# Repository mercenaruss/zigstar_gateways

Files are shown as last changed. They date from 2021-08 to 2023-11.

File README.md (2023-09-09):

# ZigStar Zigbee Gateways
Information and documentation on ZigStar gateways is available on [Website](https://zig-star.com) <br/> 
Pre-assembed hardware devices can be purchased from [https://zig-star.com](https://zig-star.com) and on [Tindie](https://www.tindie.com/stores/zigstar/)<br />



ZigStar Zigbee Gateways have next features:

-   It's using CC2652P TI chip from TI, the most powerful (+20dB)
-   **2 WORKING MODES:** LAN Coordinator or USB Coordinator/Router
-   Required buttons are on board (BOOT,FLASH,RESET)
-   2 LED for indication of network
-   Communicates via USB or LAN network with  [Z2M](https://www.zigbee2mqtt.io/)  and  [ZHA](https://www.home-assistant.io/integrations/zha/)
-   SMA port for an external antenna
-   Easy programming with  [ZigStar Multi Tool](https://zig-star.com/radio-docs/zigstar-multi-tool/#zigstar-multi-tool).No external programmer needed!
-   All boards are OpenSource,ready for self assembly

## Active Devices
| Picture 	| Device 	| Description 	| Working Mode 	|
|---	|---	|---	|---	|
| uzg-01  	| [UZG-01](https://uzg.zig-star.com/) 	| Custom device without modules 	| USB/LAN/WIFI 	|
| lan-gateway  	| [ZigStar LAN Gateway](https://zig-star.com/projects/zigbee-gw-lan/) 	| CC2652P2 & WT32-ETH01 ESP32 	| USB/LAN 	|
| usb-stick 	| [ZigStar Stick v4](https://zig-star.com/projects/zigbee-stick-v4/) 	| CC2652P2 	| USB 	|

## Retired devices
| Picture 	| Device 	| Description 	| Working Mode 	|
|---	|---	|---	|---	|
| poe-gateway 	| [ZigStar OliZig PoE](https://zig-star.com/projects/zigstar-olizig/) 	| CC2652P2 & Olimex ESP32-PoE 	| USB/LAN/POE  	|
| poe-gateway 	| [ZigStar LilyZig PoE](https://zig-star.com/projects/zigstar-lilyzig/) 	| CC2652P2 & TTGO T-Internet-POE 	| USB/LAN/POE  	|

## Development

For all documentation,description and instructions visit: [ZIG-STAR.COM](https://zig-star.com)<br>
In case you want to help us improve documentation please check documentation subfolder.

## Contact

For general enquiries, suggestions and errors spotted contact me using:

- [Telegram Chat](https://t.me/zig_starting)

- [Telegram News](https://t.me/zigstar)

- [Twitter](https://twitter.com/zig_star4u)

- [Discord](https://discord.gg/zPMT3GvvdC)

- [support@zig-star.com](mailto:support@zig-star.com)

### License
zigstar-gateways is designed by ZigStar / Grecu Radu and licensed under the [GPL-3.0 License](https://opensource.org/licenses/GPL-3.0).

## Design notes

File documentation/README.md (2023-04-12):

# ZigStar Gateways -  Documentation

This subfolder contains the [zig-star.com](https://zig-star.com) documentation.
It is based on [Mkdocs](https://www.mkdocs.org/) & [Material for MkDocs](https://squidfunk.github.io/mkdocs-material/)

You are very welcome to help on improving documentation.

## Directory-Structure

* `docs`: The actual documentation.
* `overrides`: MkDocs enhancements.
* `mkdocs.yaml`: MkDocs config file
* `init_setup.sh`: Prepare venv enviroment 
* `requirements.txt`: Mkdocs requirements

## Mkdocs installation

```bash
# Install MkDocs dependencies Linux
bash init_setup.sh
```

Manual installation:
```bash
# Install MkDocs dependencies Windows
python3 -m venv venv
. venv/Scripts/activate
pip install mkdocs-material
```

## Live preview of changes

From documentation folder run next commands:
```bash
# Enter in virtual enviroment
. venv/bin/activate ##For Linux
. venv/Scripts/activate  ## For windows
# Run mkdocs serve command to generate live preview
mkdocs serve
```

## Requirements:

- Python 3.8+
- pip

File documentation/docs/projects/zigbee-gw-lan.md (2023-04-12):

---
title: ZigStar LAN Gateway
description: Zigbee LAN Coordinator based on CC2652P
tags:
  - zigbee gateway lan
  - zigbee ethernet gateway
  - zigbee lan bridge
  - ethernet zigbee
  - zigbee ethernet
  - lan coordinator
hide:
  - tags
  - toc
---

<div class="swiper stick">
      <div class="swiper-wrapper">
        <div class="swiper-slide">
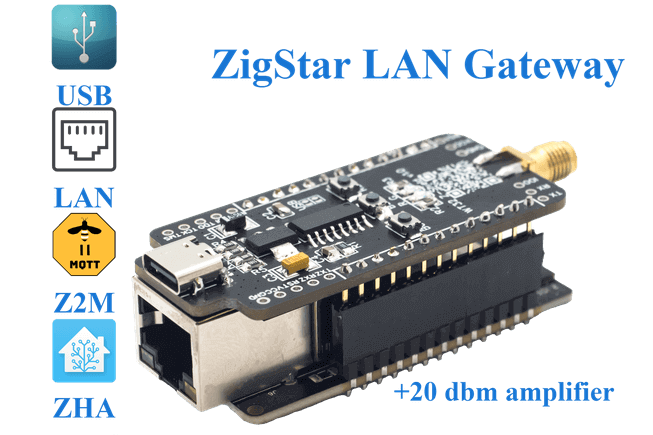
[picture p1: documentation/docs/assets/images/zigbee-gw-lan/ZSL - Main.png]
”zigbee
          
        </div>
    <div class="swiper-slide">
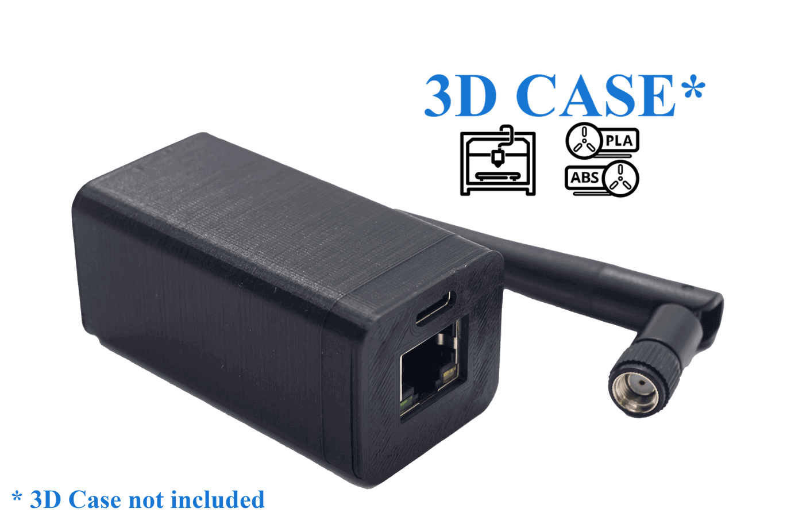
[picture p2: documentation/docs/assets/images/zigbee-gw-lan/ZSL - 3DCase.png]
”zigbee
          
        </div>
      </div>

    </div>

## Features

- Wide range of Zigbee Modules (CC2652P, CC2652RB, etc)
- <b> 2 WORKING MODES: </b> LAN Coordinator or USB Coordinator/Router
- BOOT,FLASH,RESET Buttons
- 2 LED for indication [Custom firmware](https://github.com/jethome-ru/zigbee-firmware/tree/master/ti/coordinator/cc2652)
- Communicates via USB or LAN network with [Z2M](https://www.zigbee2mqtt.io/) and [ZHA](https://www.home-assistant.io/integrations/zha/)
- SMA port for an external antenna
- Easy programming with [ZigStar Multi Tool](/radio-docs/zigstar-multi-tool/#zigstar-multi-tool).No external programmer needed!<br>
- Plug & Play, comes pre-flashed

## Revisions

There are 3 version of Zigbee LAN Gateway,what are tested:<br>
- [RF-STAR RF-BM-2652P2 - 20dBm](https://github.com/mercenaruss/zigstar_gateways/raw/main/files/Gerbers/LAN%20Gateway/Gerber_WT32_RF-BM-2652P2.zip)<br>
- [Ebyte E72-2G4M20S1E  - 20dBm](https://github.com/mercenaruss/zigstar_gateways/raw/main/files/Gerbers/LAN%20Gateway/Gerber_WT32_E72-2G4M20S1E.zip)<br> 
- [Ebyte E72-2G4M05S1F  - 5dBm](https://github.com/mercenaruss/zigstar_gateways/raw/main/files/Gerbers/LAN%20Gateway/Gerber_WT32_E72-2G4M05S1F.zip)[^1]<br>

!!! INFO
    - RF-STAR RF-BM-2652P2 recommended
	  - PCB thickness 1.2mm is recommended

## Bill of Materials

EasyEDA Generated BOM,you can order on [LCSC](https://lcsc.com) directly - [BOM](https://github.com/mercenaruss/zigstar_gateways/blob/main/files/BOM/BOM_WT32_RF-BM-2652P2.csv)

| Designator  | Name  | Footprint | Quantity |
| :---|:---|:-----|:---:|
| U1|[RF-BM-2652P1/P2](https://letyshops.com/r/aliexpress-c83c7878b18b)| | 1 |
| U2|[WT32-ETH01](https://letyshops.com/r/aliexpress-73b6cc1c03c9) |N/A| 1 |
| U3 | CH340C|SOP-16 |1|
| U4 | AMS1117-3.3|SOT-223 |1|
| R1 | 10 kohm|SMD 0805 |1|
| R2,R3 | 1 kohm|SMD 0805 |2|
| R4,R5 | 5.1 kohm|SMD 0805 |2|
| R6,R7 | 22 ohm|SMD 0805 |2|
| C1| 10uF|SMD_L3.5-W2.8|1|
| C2,C4| 100nF|SMD 0805|2|
| C3| 22uF|SMD_L3.5-W2.8|1|
| L1,L2| RED/GREEN LED|SMD 0805|2|
| SBL,RST,BOOT|PUSH BUTTON |SMD_L3.9-W3.0-P4.45|3|
| USB| TYPE-C|USB-C_SMD-TYPE-C-31-M-12|1|
| CON| [STACKABLE HEADER 13 PIN](https://letyshops.com/r/aliexpress-09c274fbb012) |2.54x13P|1|
| ANT| [SMA ANTENNA PORT 1.2mm](https://letyshops.com/r/aliexpress-e6704ce906c0)|SMA EDGE|1|

Next items are not available on LCSC,you can get them on Aliexpress:

| Name  | Shop 1 | Shop 2 |
| :---|:---|:-----|
| WT32-ETH01| [CLICK](https://letyshops.com/r/aliexpress-a4dd8609c8d4)| [CLICK](https://letyshops.com/r/aliexpress-401d07dc02d1) |
| RF-STAR RF-BM-2652P1/P2|[CLICK](https://letyshops.com/r/aliexpress-dbe513b72282) | [CLICK](https://letyshops.com/r/aliexpress-1f3e1a35e82d) |
| Ebyte E72-2G4M20S1E | [CLICK](https://letyshops.com/r/aliexpress-b25ea4b8642a)| [CLICK](https://letyshops.com/r/aliexpress-00563b7dcf47) |
| Ebyte E72-2G4M05S1F | [CLICK](https://letyshops.com/r/aliexpress-dd63f3c1afdc)| [CLICK](https://letyshops.com/r/aliexpress-c8b5adc0e26c) |
| RP-SMA Antenna PCB Connector 1.2mm | [CLICK](https://letyshops.com/r/aliexpress-7507f61580c3)| N/A |
| RP-SMA Antenna Female - Inner hole |[CLICK](https://letyshops.com/r/aliexpress-81d294a1360f)| [CLICK](https://letyshops.com/r/aliexpress-5ebae68206ac) |
| STACKABLE FEMALE HEADER 13 PIN| [CLICK](https://letyshops.com/r/aliexpress-fb2fa1673785) | [CLICK](https://letyshops.com/r/aliexpress-09c274fbb012) |

## Options

In order to use your LAN Gateway in USB Mode(without connection to WT32-ETH01):<br>
Solder jumpers, labeled J1/USB or change default DIP switch position

!!! danger "DIP Switch Positions"
    - <b>ON</b> for USB Mode
	  - <b>OFF</b> for LAN Mode<br>

    Both switches should be in the same position.
  
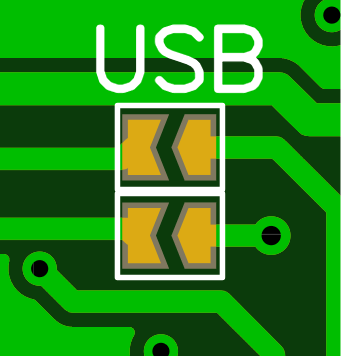
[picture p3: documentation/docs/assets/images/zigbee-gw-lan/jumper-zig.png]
Jumper-Zigbee
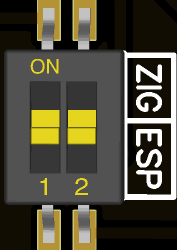
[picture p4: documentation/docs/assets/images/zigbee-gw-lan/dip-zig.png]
Jumper-Zigbee
  

## Firmware

Help on choosing correct firmware for your device is located [HERE](/radio-docs/quick-start/#step-2-download-the-correct-firmware-for-your-device)

## Flashing

* [YAML Config](https://github.com/mercenaruss/zigstar_gateways/blob/main/files/ESP-HOME/zigstar-gw-lan.yaml)<br>
* [WT32-ETH01 Firmware ESP-Home](https://github.com/mercenaruss/zigstar_gateways/raw/main/files/ESP-HOME/zigstar-gw-lan.bin)<br> 
* [ZigStar Firmware](https://github.com/xyzroe/ZigStarGW-FW/releases)[^2]<br> 
* ESP-HOME flashing guide - [ESP-HOME](/radio-docs/esp-home/)<br>
* ZigStar flashing guide - [ZigStar Firmware](/radio-docs/flash-zigstargw/)<br>
* Zigbee Module flashing guide - [ZigStar Multi Tool](/radio-docs/zigstar-multi-tool/#zigstar-multi-tool))<br>

## Downloads
 - [Gerbers](https://github.com/mercenaruss/zigstar_gateways/tree/main/files/Gerbers)
 - [STL Case](https://github.com/mercenaruss/zigstar_gateways/tree/main/files/STL)
 - [Schematics (pdf)](https://github.com/mercenaruss/zigstar_gateways/tree/main/files/Schematics)
 - [LCSC BOM File](https://github.com/mercenaruss/zigstar_gateways/tree/main/files/BOM)

## Video

*English subtitles available

1. Ethernet Zigbee ZigStar Gateway, installing multiple zigbee2mqtt<br>

	<iframe width="560" height="315" src="https://www.youtube-nocookie.com/embed/KBEaVZyvSgY" title="YouTube video player" frameborder="0" allow="accelerometer; autoplay; clipboard-write; encrypted-media; gyroscope; picture-in-picture" allowfullscreen></iframe>

2. Server redundancy with Zigbee2MQTT on Zigbee LAN Coordinator Zigstar<br>

	<iframe width="560" height="315" src="https://www.youtube-nocookie.com/embed/g7BpjCrOhk8" title="YouTube video player" frameborder="0" allow="accelerometer; autoplay; clipboard-write; encrypted-media; gyroscope; picture-in-picture" allowfullscreen></iframe>
	
[^1]: **Not recommended for new assembly.**
[^2]: **All forces will be used for this firmware, ESPHOME debugging and development is depreceated**

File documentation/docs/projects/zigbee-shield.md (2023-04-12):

---
title: ZigStar Shield
description: Zigbee Shield (CC2652P Zigbee Coordinator) Design Files and Description, working with Zigbee2Mqtt (Z2M) and ZHA
---

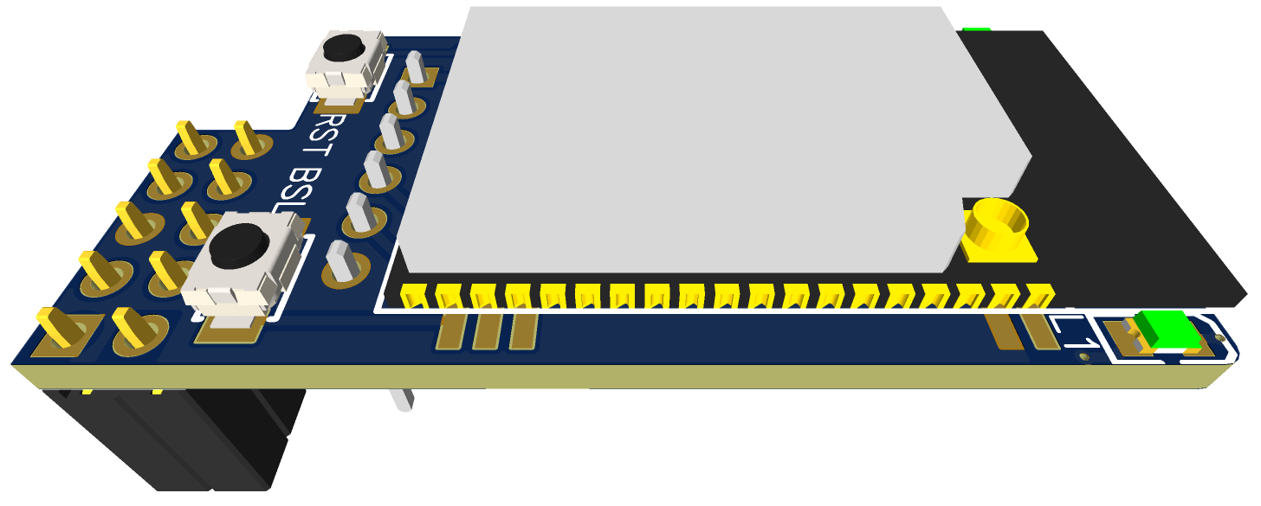
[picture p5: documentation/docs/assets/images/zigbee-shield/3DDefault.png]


## Features

- [TI CC2652P](https://www.ti.com/product/CC2652P)SimpleLink™ 2.4 GHz Multiprotocol Wireless MCU targeting Zigbee,Bluetooth 5.1 Low Energy,Thread + 19.5-dBm high-power amplifier
- Support RF-BM-2652P1 and RF-BM-2652P2 Module from RF-STAR,with CC2652P on board
- BSL,RST Buttons
- 2 LED for indication
- Compatible with [Z2M](https://www.zigbee2mqtt.io/) and [ZHA](https://www.home-assistant.io/integrations/zha/)
- IPX port for an external antenna
- Self-programming via [cc2538-bsl](https://github.com/JelmerT/cc2538-bsl). No external programmer needed! Push BSL button to trigger this mode.

## Bill of Materials:

EasyEDA Generated Boom,you can order on [LCSC](https://lcsc.com)directly - [BOOM](https://github.com/mercenaruss/zigbee-stick-v4/blob/main/files/BOM_ZigStar_Shield.csv)

| Designator  | Name  | Footprint | Quantity |
| :---|:---|:-----|:---:|
| U1| RF-BM-2652P1/P2| | 1 |
| U2|AMS1117-3.3 |SOT-223| 1 |
| R1 | 10 kohm|SMD 0805 |1|
| R2,R3 | 1 kohm|SMD 0805 |2|
| C1| 10uF|SMD_L3.5-W2.8-R-RD|1|
| C2| 22uF|SMD_L3.5-W2.8-R-RD|1|
| C3| 100nF|SMD 0805|1|
| L1,L2| RED/GREEN LED|SMD 0805|2|
| SBL,RST|PUSH BUTTON |SMD_L3.9-W3.0-P4.45|2|
| JTAG| PIN HEADER 5 PIN|2.54x5P|1|
| H1| FEMALE HEADER 2x5 PIN|2.54 2x5P|1|

Next item is not available on LCSC,you can get it on Aliexpress:

 - [RF-BM-2652P1/P2](https://letyshops.com/r/aliexpress-f6e2c6d280d5)
 
## Firmware

Module is compatible with [Z2M](https://www.zigbee2mqtt.io/).
Firmware [CC1352P2_CC2652P_launchpad_*.zip](https://github.com/Koenkk/Z-Stack-firmware/tree/master/coordinator/Z-Stack_3.x.0/bin).<br>
Default TX Power is <b>5dbm</b>. It can be adjusted in Z2M config section:

    experimental:
      transmit_power: 5

Available TX power values: -20,-18,-15,-12,-10,-9,-6,-5,-3,0,1..5,14..20

## Downloads
 - [Gerber](https://github.com/mercenaruss/zigbee-stick-v4/tree/main/files/gerber)
 - [Schematics (pdf), Revision 1](https://github.com/mercenaruss/zigbee-stick-v4/tree/main/files/schematics)
 - [LCSC Boom File](https://github.com/mercenaruss/zigbee-stick-v4/blob/main/files/BOM_ZigStar_Shield.csv)

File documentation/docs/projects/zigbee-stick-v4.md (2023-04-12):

---
title: ZigStar Stick v4
description: Zigbee USB Stick - CC2652P Zigbee Coordinator
tags:
  - zigbee stick
  - zigbee usb-stick
  - usb zigbee gateway
  - zigbee dongle
  - zigbee coordinator
hide:
  - tags
  - toc
---
<div class="swiper stick">
      <div class="swiper-wrapper">
        <div class="swiper-slide">
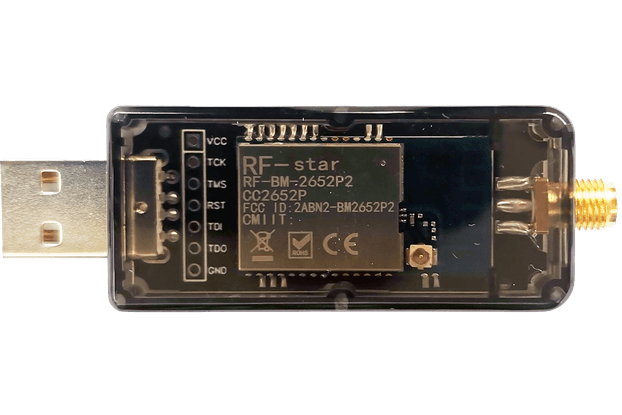
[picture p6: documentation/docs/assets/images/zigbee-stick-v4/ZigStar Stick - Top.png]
”zigbee
          
		  <div class="title" id="title_1">ZigStar Stick - Top</div>
        </div>
        <div class="swiper-slide">
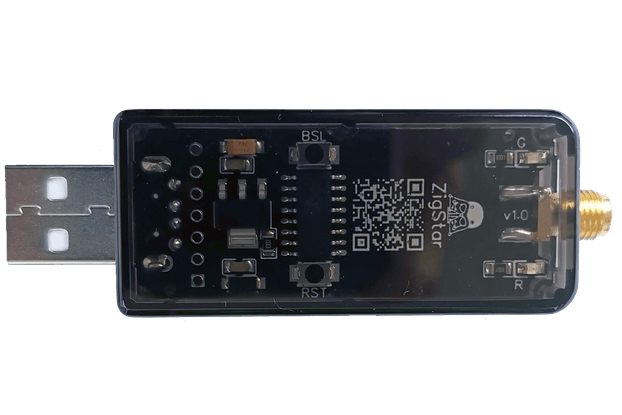
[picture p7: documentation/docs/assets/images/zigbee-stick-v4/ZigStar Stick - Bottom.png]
”cc2652p
          
		  <div class="title" id="title_2">ZigStar Stick - Bottom</div>
        </div>
      </div>

    </div>

## Features

- [TI CC2652P](https://www.ti.com/product/CC2652P) SimpleLink™ 2.4 GHz Multiprotocol Wireless MCU targeting Zigbee,Bluetooth 5.1 Low Energy,Thread + 19.5-dBm high-power amplifier<br>
- Support RF-BM-2652P1 and RF-BM-2652P2 Module from RF-STAR,with CC2652P on board<br>
- BSL,RST Buttons<br>
- 2 LED for indication<br>
- Compatible with [Z2M](https://www.zigbee2mqtt.io/)and [ZHA](https://www.home-assistant.io/integrations/zha/)<br>
- SMA antenna port for an external antenna<br>
- Easy programming with [ZigStar Multi Tool](/radio-docs/zigstar-multi-tool/#zigstar-multi-tool).No external programmer needed!<br>
- Communicates via the common CH340E/CH340C USB-UART Bridge<br>
- Plug & Play, comes pre-flashed<br>

## Purchase 

Assembled versions of Zigbee Stick v4 is available for purchase.<br>
<b>Shiping is done from Germany</b><br>
Each order contains a fully assembled and tested PCBA along with a plastic enclosure and a small +3dBi antenna.

## Revisions

There are 2 versions of stick,both of them tested:<br>
- [CH340C 3D Printed Case version](https://github.com/mercenaruss/zigbee-stick-v4/raw/main/files/gerber/Gerber_Zigbee%20Stick%20v4.0%20-%20CH340C.zip), more easy to solder,Auto-BSL enabled and includes ESD protection.[^1]<br>
- [CH340C Factory Case version](https://github.com/mercenaruss/zigbee-stick-v4/raw/main/files/gerber/Gerber_Zigbee%20Stick%20v4.0%20-%20CH340C%20-%20Factory%20VG-S48_AK-N-12.zip),[^2] fits in this factory cases [VG-S48](https://letyshops.com/r/aliexpress-5891f3cb4a88)/[AK-N-12](https://letyshops.com/r/aliexpress-0f3a529a9464)<br>

CH340C versions use this [3D Model Case](https://github.com/mercenaruss/zigbee-stick-v4/blob/main/files/STL)<br>
Factory cases are found on Aliexpress: [VG-S48](https://letyshops.com/r/aliexpress-5891f3cb4a88)/[AK-N-12](https://letyshops.com/r/aliexpress-0f3a529a9464) 

## Bill of Materials:

EasyEDA Generated Boom,you can order on [LCSC](https://lcsc.com)directly - [BOM](https://github.com/mercenaruss/zigbee-stick-v4/blob/main/files/BOM_Zigbee%20Stick%204.0%20CH340E-C.csv)

| Designator  | Name  | Footprint | Quantity |
| :---|:---|:-----|:---:|
| U1| RF-BM-2652P1/P2| | 1 |
| U2|AMS1117-3.3 |SOT-223| 1 |
| U3 | CH340E/CH340C|MSOP-10/SOP-16 |1|
| R1 | 10 kohm|SMD 0805 |1|
| R2,R3 | 1 kohm|SMD 0805 |2|
| R4 | 100 ohm|SMD 0805 |1|
| C1| 10uF|SMD_L3.2-W1.6|1|
| C2,C4| 100nF|SMD 0805|2|
| C3| 22uF|SMD_L3.2-W1.6|1|
| L1,L2| RED/GREEN LED|SMD 0805|2|
| SBL,RST|PUSH BUTTON |SMD_L3.9-W3.0-P4.45|2|
| USB| USB A MALE|USB-A-SMD_USB-A-1-TH|1|
| JTAG| PIN HEADER 5 PIN|2.54x5P|1|
| ANT| SMA ANTENNA PORT 1.6mm||1|
| D1| ESD USBLC6-2SC6|SOT-23-6|1|

**WARNING** D1 is used only for CH340C and Factory Case sticks.<br>
Next items are not available on LCSC,you can get them on Aliexpress:<br>
 - [RF-BM-2652P1/P2](https://letyshops.com/r/aliexpress-c83c7878b18b)<br> 
 - [RP-SMA Antenna PCB Connector 1.2/1.6mm](https://letyshops.com/r/aliexpress-7507f61580c3)<br> 
 - [RP-SMA Antenna Female - Inner hole](https://letyshops.com/r/aliexpress-81d294a1360f)<br> 
 - Cases [VG-S48](https://letyshops.com/r/aliexpress-5891f3cb4a88)/[AK-N-12](https://letyshops.com/r/aliexpress-0f3a529a9464)<br> 
 
## Firmware

Module is compatible with [Z2M](https://www.zigbee2mqtt.io/).
Firmware [CC1352P2_CC2652P_launchpad_*.zip](https://github.com/Koenkk/Z-Stack-firmware/tree/master/coordinator/Z-Stack_3.x.0/bin).<br>
Default TX Power is <b>9dbm</b>. It can be adjusted in Z2M config section:

    experimental:
      transmit_power: 10

Available TX power values: -20,-18,-15,-12,-10,-9,-6,-5,-3,0,1..5,14..20 [^3]

## Downloads
 - [Gerbers](https://github.com/mercenaruss/zigbee-stick-v4/tree/main/files/gerber)<br> 
 - [STL Case](https://github.com/mercenaruss/zigbee-stick-v4/tree/main/files/STL)<br>
 - [Schematics (pdf), Revision 1](https://github.com/mercenaruss/zigbee-stick-v4/tree/main/files/schematics)<br> 
 - [LCSC Boom File](https://github.com/mercenaruss/zigbee-stick-v4/blob/main/files/BOM_Zigbee%20Stick%204.0%20CH340E-C.csv)<br>
 
## Video

*English subtitles available

<iframe width="560" height="315" src="https://www.youtube.com/embed/vhDZYdSpEH4" title="YouTube video player" frameborder="0" allow="accelerometer; autoplay; clipboard-write; encrypted-media; gyroscope; picture-in-picture" allowfullscreen></iframe>

[^1]: **Not recomended for new assembly.**
[^2]: **Recomended version for assembly.**
[^3]: **After many tests recomended value is 10dbm, depending on your environment.**

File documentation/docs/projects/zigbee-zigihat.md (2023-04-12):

---
title: ZigStar ZigiHAT
description: Raspberry HAT - Zigbee Coordinator
tags:
  - raspberry coordinator
  - raspberry zigbee shield
  - raspberry hat
  - zigihat
hide:
  - tags
  - toc
---

<div class="swiper stick">
      <div class="swiper-wrapper">
        <div class="swiper-slide">
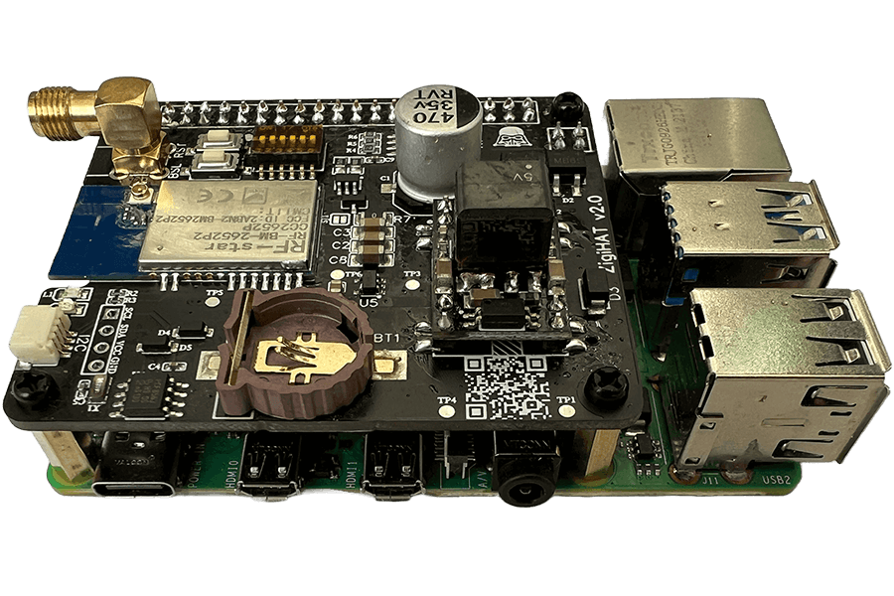
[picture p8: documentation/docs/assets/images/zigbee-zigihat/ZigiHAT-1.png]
”zigbee
          
        </div>
    <div class="swiper-slide">
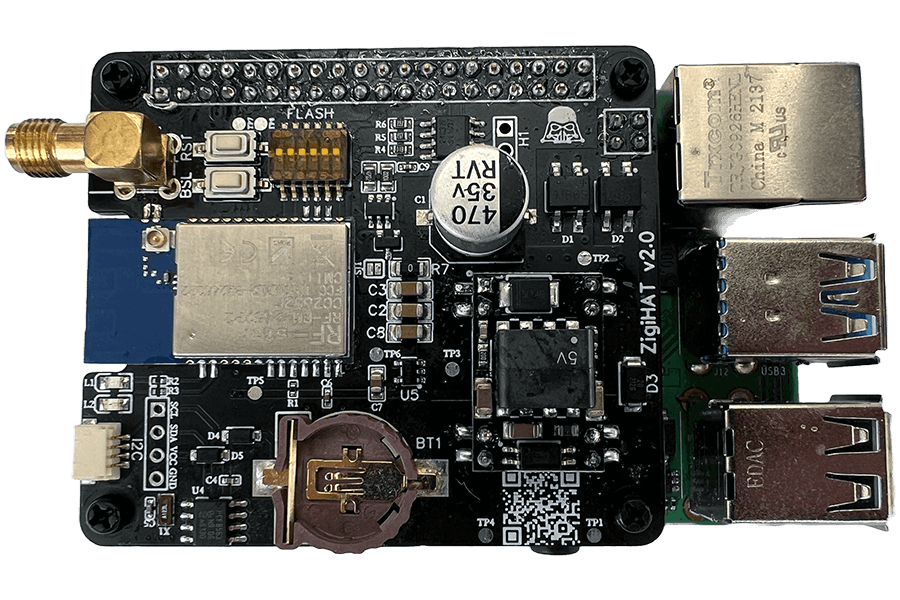
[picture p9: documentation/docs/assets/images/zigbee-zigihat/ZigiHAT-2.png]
”zigbee
          
        </div>
      </div>

    </div>

## Features
- [CC2652P](https://www.ti.com/product/CC2652P)chip from Texas Instruments, using the [RF-BM-2652P2](https://letyshops.com/r/aliexpress-c83c7878b18b)module:
    - Max. RF Power: 20dBm
    - Built-in ROM serial bootloader - no external programmer/debugger needed
- SMA antenna for 2.4GHz(ZigBee)
- PoE IEEE 802.3af or passive 48V PoE support
- RTC with backup battery for offline timekeeping
- ID EEEPROM (firmware still under development)
- Easy programming using [CC2538-BSL](https://github.com/JelmerT/cc2538-bsl)or [OpenOCD](https://openocd.org/)JTAG([scripts provided](#flashing))
- QWIIC/Stemma QT compatible I2C expansion header
- BSL,RESET Buttons

## What is included:
- ZigiHAT Addon board - 1 pcs
- Standoff - 4 pcs
- Plastic screws - 4 pcs

## Flashing

To make setup and flashing procedure more pleasant for end-user,we make some scripts to be used for setup of ZigiHAT<br>

- <b>Pi_Flasher_CC2538</b> - Run to flash last [Koenkk firmware](https://github.com/Koenkk/Z-Stack-firmware)using [CC2538-BSL](https://github.com/JelmerT/cc2538-bsl)<br>
  ```
	curl -s https://raw.githubusercontent.com/mercenaruss/zigstar_gateways/main/files/Tools/Scripts/Pi_Flasher_CC2538.sh > Pi_Flasher_CC2538.sh && chmod +x ./Pi_Flasher_CC2538.sh && ./Pi_Flasher_CC2538.sh
  ```
- <b>Pi_Flasher_JTAG</b> - Run to flash over JTAG the last [Koenkk firmware](https://github.com/Koenkk/Z-Stack-firmware)using [OpenOCD](https://openocd.org/)
  ```
  curl -s https://raw.githubusercontent.com/mercenaruss/zigstar_gateways/main/files/Tools/Scripts/Pi_Flasher_JTAG.sh > Pi_Flasher_JTAG.sh && chmod +x ./Pi_Flasher_JTAG.sh && ./Pi_Flasher_JTAG.sh
  ```
- <b>Pi_Starter</b> - Run to setup your Raspberry Pi Wifi/Bluetooth, RTC and I2C,what is available on board of ZigiHAT
  ```
  curl -s https://raw.githubusercontent.com/mercenaruss/zigstar_gateways/main/files/Tools/Scripts/Pi_Starter.sh > Pi_Starter.sh && chmod +x ./Pi_Starter.sh && ./Pi_Starter.sh
  ```

!!! tip
      
    Wifi and Bluetooth is recomended to disable in case in not used by system,when <b>Pi_Starter</b> ask you. 

??? danger "Flashing settings"
    In order to use any of flashing methods(<b>Pi_Flasher_CC2538</b> or <b>Pi_Flasher_JTAG</b>),all swithes from DIP switch(FLASH) should be in ON position.

## Downloads

- [Gerbers](https://github.com/mercenaruss/zigstar_gateways/tree/main/files/Gerbers)
- [Schematics](https://github.com/mercenaruss/zigstar_gateways/tree/main/files/Schematics)
- [LCSC BOM File](https://github.com/mercenaruss/zigstar_gateways/tree/main/files/BOM)

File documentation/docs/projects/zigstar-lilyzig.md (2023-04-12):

---
title: ZigStar LilyZig
description: ZigStar Zigbee POE Coordinator based on CC2652P.
tags:
  - zigbee gateway poe
  - zigbee poe coordinator
  - zigbee ethernet gateway
  - zigbee poe bridge
  - ethernet zigbee
  - zigbee ethernet
hide:
  - tags
  - toc
---

<div class="swiper stick">
      <div class="swiper-wrapper">
        <div class="swiper-slide">
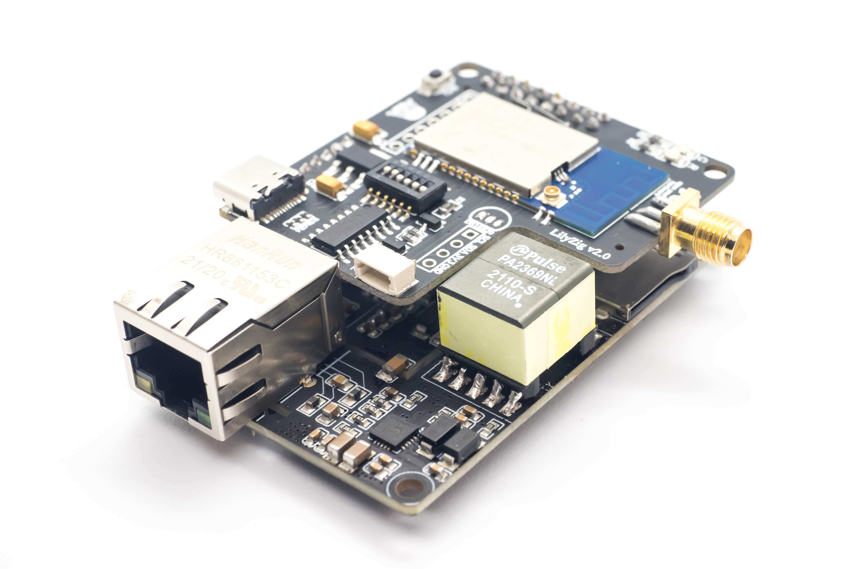
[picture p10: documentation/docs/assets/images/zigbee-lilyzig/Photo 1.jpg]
”zigbee
          
        </div>
        <div class="swiper-slide">
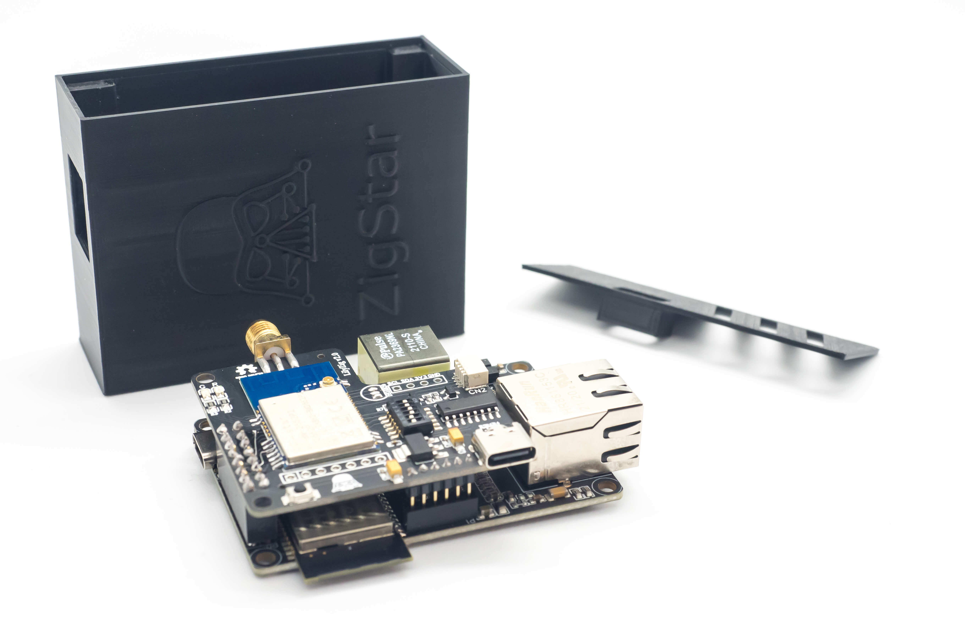
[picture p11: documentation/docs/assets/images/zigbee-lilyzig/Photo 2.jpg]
”zigbee
          
        </div>
		<div class="swiper-slide">
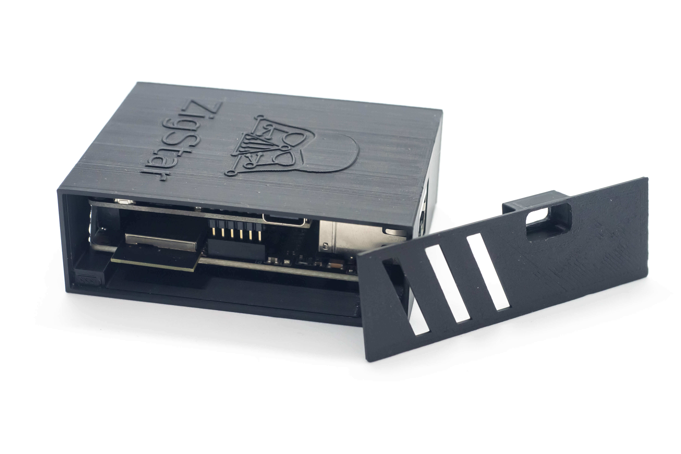
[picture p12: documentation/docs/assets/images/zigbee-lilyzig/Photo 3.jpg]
”zigbee
          
        </div>
		<div class="swiper-slide">
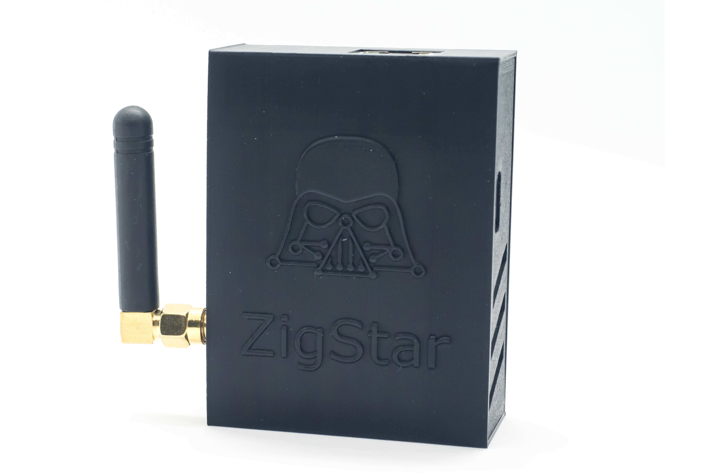
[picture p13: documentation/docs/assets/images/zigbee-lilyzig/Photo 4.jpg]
”zigbee
          
        </div>
      </div>

    </div>

!!! note

    **LiliZig is retired** Not anymore on sale. Available only for self assembly.

## Features

- <b>802.3af PoE</b> or USB C-Type [^1]
- CC2652P TI chip, the most powerful (+20dB)
- <b> 2 WORKING MODES: </b> LAN/POE Coordinator or USB Coordinator/Router
- 2 LED for indication [KoenK Firmware](https://github.com/Koenkk/Z-Stack-firmware/tree/master/coordinator/Z-Stack_3.x.0/bin)
- Communicates via USB or LAN network with [Z2M](https://www.zigbee2mqtt.io/) and [ZHA](https://www.home-assistant.io/integrations/zha/)
- SMA port for an external antenna
- Easy programming with [ZigStar Multi Tool](/radio-docs/zigstar-multi-tool/#zigstar-multi-tool). No external programmer needed!<br>

!!! danger "Important notice"
    **USB and PoE is forbidden to use simultaneously!**<br>
    LilyZig has **no galvano isolation** from Ethernet's power supply, when you program the board via the USB-C connector the Ethernet cable should be disconnected.

## Revisions

There are 2 version of LilyZig POE Gateway,what are tested:<br>
- [RF-STAR RF-BM-2652P2 - 20dBm](https://github.com/mercenaruss/zigstar_gateways/raw/main/files/Gerbers/LilyZig/Gerber_TTGO_RF-BM-2652P2.zip)<br>
- [Ebyte E72-2G4M20S1E  - 20dBm](https://github.com/mercenaruss/zigstar_gateways/raw/main/files/Gerbers/LilyZig/Gerber_TTGO_E72-2G4M20S1E.zip)<br> 

!!! INFO
    - RF-STAR RF-BM-2652P2 recommended
	  - PCB thickness 1.2mm is recommended

## Bill of Materials

EasyEDA Generated BOM,you can order on [LCSC](https://lcsc.com) directly - [BOM](https://github.com/mercenaruss/zigstar_gateways/blob/main/files/BOM/BOM_TTGO_RF-BM-2652P2.csv)

Next items are not available on LCSC,you can get them on Aliexpress:

| Name  | Shop 1 | Shop 2 |
| :---|:---|:-----|
| LILYGO® TTGO T-Internet-POE| [CLICK](https://letyshops.com/r/aliexpress-69affae66921)| [CLICK](https://letyshops.com/r/aliexpress-95230416106d)|
| RF-STAR RF-BM-2652P1/P2|[CLICK](https://letyshops.com/r/aliexpress-c83c7878b18b) | [CLICK](https://letyshops.com/r/aliexpress-dbe513b72282) |
| Ebyte E72-2G4M20S1E | [CLICK](https://letyshops.com/r/aliexpress-b25ea4b8642a)| [CLICK](https://letyshops.com/r/aliexpress-00563b7dcf47) |
| RP-SMA Antenna PCB Connector 1.2mm | [CLICK](https://letyshops.com/r/aliexpress-7507f61580c3)| N/A |
| RP-SMA Antenna Female - Inner hole |[CLICK](https://letyshops.com/r/aliexpress-81d294a1360f)| [CLICK](https://letyshops.com/r/aliexpress-5ebae68206ac) |

## Firmware

Help on choosing correct firmware for your device is located [HERE](/radio-docs/quick-start/#step-2-download-the-correct-firmware-for-your-device)

## Flashing

* [ZigStar ESP Firmware!](https://github.com/xyzroe/ZigStarGW-FW/releases)[^2]<br> 
* Zigbee Module flashing guide - [ZigStar Multi Tool](/radio-docs/zigstar-multi-tool/#zigstar-multi-tool))<br>

## Downloads
 - [Gerbers](https://github.com/mercenaruss/zigstar_gateways/tree/main/files/Gerbers)
 - [STL Case](https://github.com/mercenaruss/zigstar_gateways/tree/main/files/STL)
 - [Schematics (pdf)](https://github.com/mercenaruss/zigstar_gateways/tree/main/files/Schematics)
 - [LCSC Boom File](https://github.com/mercenaruss/zigstar_gateways/tree/main/files/BOM)

## Video

*English subtitles available

<iframe width="560" height="315" src="https://www.youtube.com/embed/0xBRh4BmTmA" title="YouTube video player" frameborder="0" allow="accelerometer; autoplay; clipboard-write; encrypted-media; gyroscope; picture-in-picture" allowfullscreen></iframe>

[^1]: **USB and PoE is forbidden to use simultaneously**
[^2]: **All forces will be used for this firmware, ESPHOME debugging and development is depreceated**

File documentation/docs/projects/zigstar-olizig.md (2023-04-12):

---
title: ZigStar Olizig
description: Zigbee POE Coordinator based on CC2652P.
tags:
  - zigbee gateway poe
  - zigbee poe coordinator
  - zigbee ethernet gateway
  - zigbee poe bridge
  - ethernet zigbee
  - zigbee ethernet
hide:
  - tags
  - toc
---

<div class="swiper stick">
      <div class="swiper-wrapper">
        <div class="swiper-slide">
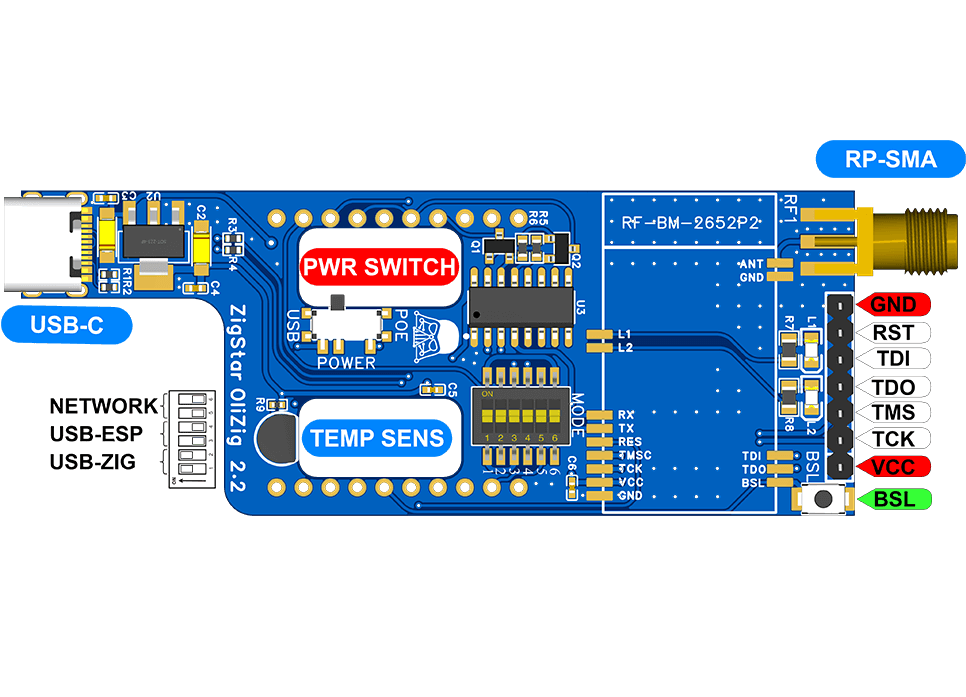
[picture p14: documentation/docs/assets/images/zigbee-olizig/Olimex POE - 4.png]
”zigbee
          
        </div>
    <div class="swiper-slide">
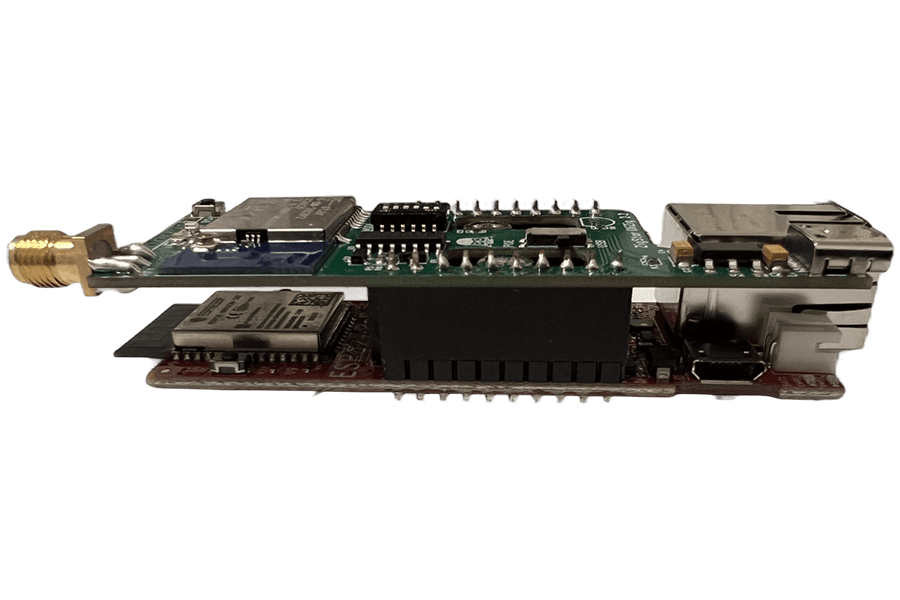
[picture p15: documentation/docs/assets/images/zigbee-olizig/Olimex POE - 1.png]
”zigbee
          
        </div>
    <div class="swiper-slide">
          <img src="../../assets/images/zigbee-olizig/Olimex POE - 3.png" alt=”olimex zigbee">
        </div>
      </div>

    </div>

## Features

- <b>802.3af PoE</b> or USB C-Type 
- CC2652P TI chip, the most powerful (+20dB)
- <b> 2 WORKING MODES: </b> LAN/POE Coordinator or USB Coordinator/Router
- 2 LED for indication [KoenK Firmware](https://github.com/Koenkk/Z-Stack-firmware/tree/master/coordinator/Z-Stack_3.x.0/bin)
- Communicates via USB or LAN network with [Z2M](https://www.zigbee2mqtt.io/) and [ZHA](https://www.home-assistant.io/integrations/zha/)
- DS18B20 temperature sensor for extra safety
- Power Switch beetween POE and USB power
- SMA port for an external antenna
- Easy programming with [ZigStar Multi Tool](/radio-docs/zigstar-multi-tool/#zigstar-multi-tool). No external programmer needed!<br>

## Flashing

* [ZigStar ESP Firmware!](https://github.com/xyzroe/ZigStarGW-FW/releases)[^1]<br> 
* Zigbee Module flashing guide - [ZigStar Multi Tool](/radio-docs/zigstar-multi-tool/#zigstar-multi-tool))<br>

## Downloads

- [Gerbers](https://github.com/mercenaruss/zigstar_gateways/tree/main/files/Gerbers)
- [Schematics](https://github.com/mercenaruss/zigstar_gateways/tree/main/files/Schematics)
- [LCSC BOM File](https://github.com/mercenaruss/zigstar_gateways/tree/main/files/BOM)

[^1]: **All forces will be used for this firmware, ESPHOME debugging and development is depreceated**

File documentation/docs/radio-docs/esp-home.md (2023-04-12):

---
title: Configuration ESP-HOME
description: ZigStar LAN Coordinator Setup Documentation
hide:
  - tags
tags:
  - ESP-HOME
  - LAN
  - WEB
---

# ESP-HOME

In order to change default setting for ESP-HOME firmware, please follow next guides.

## Install ESP-HOME 

Choose from 2 optional avalaible at the moment:

=== "HA Supervised"

	It's using Home Assistant add-on, install instruction are found [HERE](https://esphome.io/guides/getting_started_hassio.html)
	
=== "Standalone"

	It can be installed barematel or using docker( personally using on windows ), follow instructions from [HERE](https://esphome.io/guides/getting_started_command_line.html)
	
!!! info	
	For both cases is required to download .yaml for your PCB

## Substitutions

For example you want to change gateway hostname, friendly name in HA, your API and OTA passwords.

In this case edit just next items,at the beggining of .yaml file:

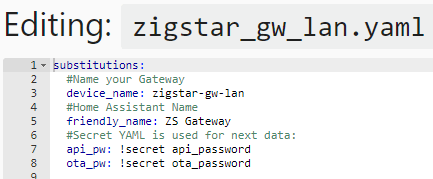
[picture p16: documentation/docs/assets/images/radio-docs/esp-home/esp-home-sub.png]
Esp-Home-Edit


## Static IP

In order to make your device have the same IP each time after reboot, you have 2 ways to achieve this: 

- setup static ip in your router config 
- modify .yaml file.

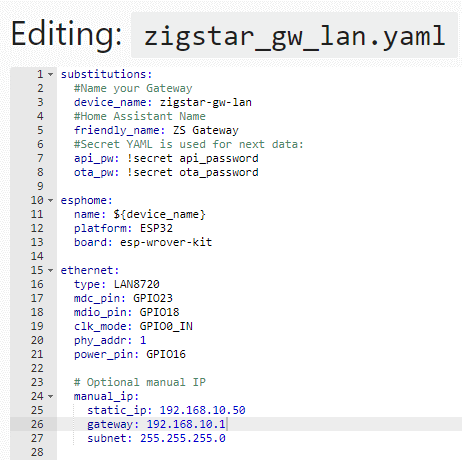
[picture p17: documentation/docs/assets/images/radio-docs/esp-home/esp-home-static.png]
Esp-Home-Static IP


## Generate and install updated firmware

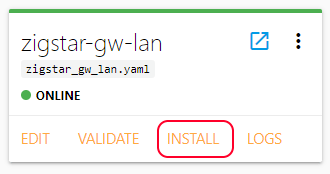
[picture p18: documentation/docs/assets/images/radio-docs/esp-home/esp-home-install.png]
Esp-Home-Install


!!! danger
	Any error in ip configuration could cause the gw to not connect and require to be flashed with Serial to USB converter( applies to Wifi Gateway)
!!! danger
	After changing IP parameters, OTA update it's not gonna work,until firmware is flashed to ESP module,using Manual Download.
		
=== "Wirelessly"

	If you made changes only in subtitutions section,then just press Install button in ESP-HOME interface,followed by Wirelessly.
	
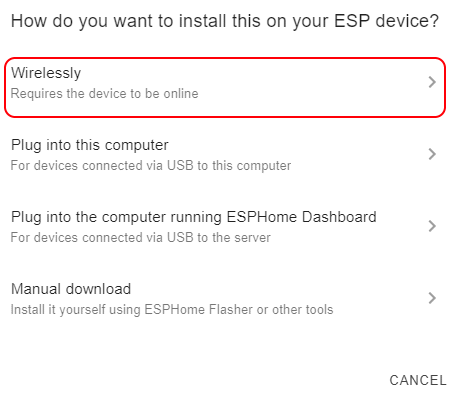
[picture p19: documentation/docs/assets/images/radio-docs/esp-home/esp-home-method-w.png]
Esp-Home-Install Wirelles1
	
	
	Esp-Home-Install Wirelles2
	
=== "Manual Download"

	After changing IP parameters, OTA update it's not gonna work,until firmware is flashed to ESP module manually.
	
	1. Press Manual Download
	
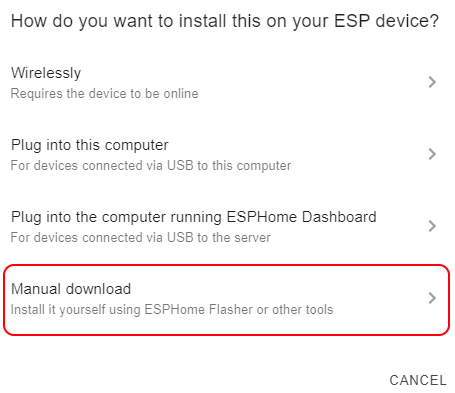
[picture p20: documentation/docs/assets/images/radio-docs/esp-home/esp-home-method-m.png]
Esp-Home-Manual Download
		
	
	2. Debug console confirm that firmware was built and Download button appear in righ bottom corner.
	
		Esp-Home-Debug Sub
	
	3. Open your gateway address in browser and update firmware:
	
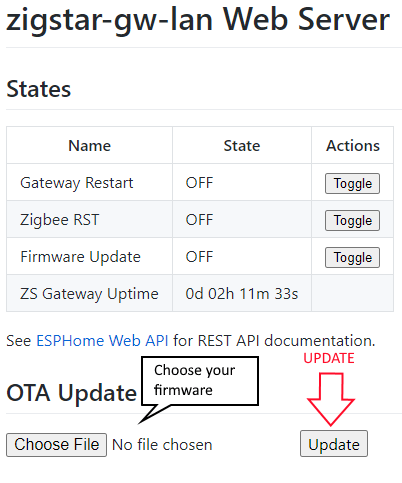
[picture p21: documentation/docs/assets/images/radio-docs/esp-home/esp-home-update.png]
Esp-Home-OTA Update


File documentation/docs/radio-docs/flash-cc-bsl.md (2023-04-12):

---
title: ZigStar Flashing Instructions
description: Instructions for flashing ZigBee Stick using cc2538-bsl
hide:
  - tags
tags:
  - cc2538-bsl
  - flashing
  - bsl
  - erase
---

# Flash Firmware using JelmerT's serial bootload tool

[JelmerT's serial bootload tool](https://github.com/JelmerT/cc2538-bsl)is a cross-platform Python script that allows you to flash firmware on TI's newer chips.<br>
All ZigStar boards are supported by cc2538-bsl.py.

## Installation

  - Install [python](https://www.python.org/downloads/)
  - Use ```python --version``` to be sure, that you are running python 3 or above!
  - If you are **NOT** running **3.4** or higher, you need to install `pip`, too.
  - Install dependencies with ```pip install pyserial intelhex```
  - Download the [cc2538-bsl.py] file or just clone the repo.<br>

Copy and paste the command into your terminal.

=== "Linux(Debian/Ubuntu)"
    ```
	sudo apt update && sudo apt-get install python3-pip
	```
	```
	wget -O cc2538-bsl.zip https://codeload.github.com/JelmerT/cc2538-bsl/zip/master && unzip cc2538-bsl.zip
	```
	```
	sudo pip3 install pyserial intelhex
	```   
=== "MacOS"
    Python3 should already be shipped with macOS,if no then follow below procedure:

	Download and extract cc2538-bsl: 
	```
	curl --output cc2538-bsl.zip https://codeload.github.com/JelmerT/cc2538-bsl/zip/master && unzip cc2538-bsl.zip
	```
	Install required dependencies: 
	```
	/usr/bin/python3 -m pip install --user pyserial intelhex
	```	
=== "Windows"

    Download [Python for Windows](https://www.python.org/downloads/)and install. After installation verify Python if its installed by running `python -V` in Command Prompt.

	If you receive a message similar to `Python is not recognized as an internal or external command, operable program or batch file.`, this means Python is either not installed or the system variable PATH hasn’t been set. You’ll need to launch Python from the folder in which it is installed or adjust your system variables to allow it to be launched from any location.

	Download the [zipped code](https://github.com/JelmerT/cc2538-bsl/archive/master.zip)and extract to a folder.

	Install required dependencies: 
	```
	pip install pyserial intelhex
	```
    !!! tip
        Please use the [Power Shell](https://docs.microsoft.com/en-us/powershell/)to have the best user experience. If you encounter permissions issues, ensure that you are running your terminal as an administrator.

## Determine the USB port/ IP address

Plug your device in and ensure that device is recognised by your OS:

=== "Linux(Debian/Ubuntu)"

    On linux, use this:
	```
	ls -l /dev/serial/by-id
	```
	Issue `dmesg` and observe the device enumeration:

	```Shell
	[152343.203201] usb 1-1.4: new full-speed USB device number 5 using dwc_otg
	[152343.336384] usb 1-1.4: New USB device found, idVendor=1a86, idProduct=7523, bcdDevice= 2.62
	[152343.336400] usb 1-1.4: New USB device strings: Mfr=0, Product=2, SerialNumber=0
	[152343.336409] usb 1-1.4: Product: USB2.0-Serial
	[152343.338315] ch341 1-1.4:1.0: ch341-uart converter detected
	[152343.341440] usb 1-1.4: ch341-uart converter now attached to ttyUSB0
	```
	
=== "MacOS"

    On macOS find the device using:
	```
	ls /dev/tty.* 
	```
	Issue `dmesg` and observe the device enumeration:
	```
	IOUserSerial::AppleUSBCHCOM::<private>: 127 0x6000013e4058
	IOUserSerial::<private>: 456 0x6000013e4058
	IOUserSerial::<private>: 41 0x6000013e4058
	DK: AppleUSBCHCOM-0x1000030ea::start(IOUSBHostInterface-0x1000030e5) ok
	```
	
=== "Windows"

    On windows, use this in a Powershell or go to Device Manager

	```
	$comports = Get-WMIObject Win32_SerialPort; $comports | Get-PnpDeviceProperty -InstanceId {$_.pnpdeviceid} -Keyname DEVPKEY_Device_BusReportedDeviceDesc | ForEach-Object { foreach($comport in $comports) { if ($comport.pnpdeviceid -eq $_.instanceid) { new-object psobject -property  @{COMPORT = $comport.deviceid; 'Device-Name' = $_.data} } } }
	```
	The drivers for CH340 should be automatically be picked up,check under "Ports (COM & LPT)" in Device Manager:

	BSL Button
	
	If you need to install the drivers manually, go [HERE](http://www.wch.cn/downloads/CH341SER_ZIP.html)for official drivers.
	
!!! TIP
        Double-check by undocking the device again.

!!! info
		For network device find out IP or hostname.
		
## Put your device in BSL mode

Please follow the following instructions to put your device in BSL mode:

=== "USB Coordinator"

	- Unplug your stick from the host
	- Press the `BSL/FLASH` pushbutton and keep holding while plugging the device back into the host
  
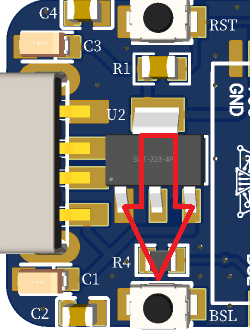
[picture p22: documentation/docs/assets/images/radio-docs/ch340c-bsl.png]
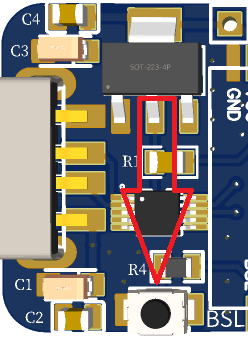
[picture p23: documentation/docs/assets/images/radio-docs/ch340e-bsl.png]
		 

	- Give it a few seconds for the device to settle and set up and release the BSL button
	- Your stick should now be in ROM bootloader mode

	<ins>It's very important that you press and hold the BSL button **before** plugging it in to the host and release it **after a few seconds**.</ins>
	!!! note
		cc2538-bsl.py and .exe supports "Auto-BSL", now you can skip the BSL pushbutton press for flashing boards.
		
		Just follow normal firmware procedure using cc2538-bsl.py or cc2538-bsl.exe. ( Boards using CH340E does not support Auto-BSL! )

=== "Network Coordinator "

	- Access device by IP or hostname using your browser
	- Click <b>Firmware Update</b>  initiate the bootloader (BSL) mode for the module:
	
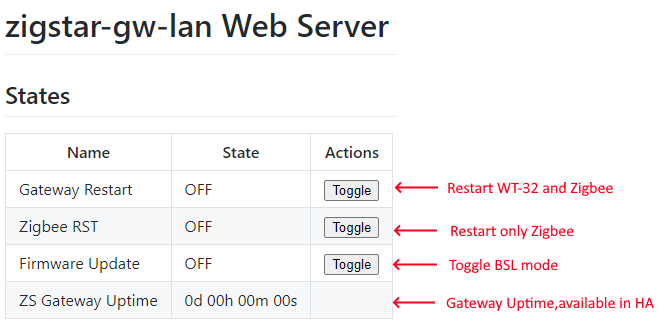
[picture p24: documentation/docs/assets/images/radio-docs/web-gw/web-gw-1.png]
	
	
	- Watch the Debug output and when promted go to next step.
	
	BSL Button
		
## Flash firmware

To flash firmware, run:

=== "Option 1 - cc2538-bsl.exe"

	```
	./cc2538-bsl.exe -p PORT -evw FIRMWARE
	```
	...where `PORT` is the serial port your board is connected to.
	```
	./cc2538-bsl.exe -p socket://ip_or_localdns_name:6638 -evw FIRMWARE
	```

=== "Option 2 - Python"

	```
	python cc2538-bsl.py -p PORT -evw FIRMWARE
	```
	...where `PORT` is the serial port your board is connected to
	```
	python cc2538-bsl.py -p socket://ip_or_localdns_name:6638 -evw FIRMWARE
	```
	
(see [above](#determine-the-usb-port)) and `FIRMWARE` is the hex file you want to flash (see [here](/radio-docs/quick-start/#step-2-download-the-correct-firmware-for-your-device) for help on choosing firmware).

!!! INFO
    -p: will select the port<br>
    -evw: will erase,write and check firmware
	
!!! warning 
	It is crucial that you download the correct firmware for your stick as using the wrong firmware will disable the BSL and you will need an external debugger / programmer to flash your stick again.</p>
	
## Additional:

### Erase device

To completely erase the device flash, run:

=== "Option 1 - cc2538-bsl.exe"

	```
	./cc2538-bsl.exe -p PORT -e
	```
	...where `PORT` is the serial port your board is connected to.
	```
	./cc2538-bsl.exe -p socket://ip_or_localdns_name:6638 -e
	```

=== "Option 2 - Python"

	```
	python cc2538-bsl.py -p PORT -e
	```
	...where `PORT` is the serial port your board is connected to.
	```
	python cc2538-bsl.py -p socket://ip_or_localdns_name:6638 -e
	```

### Clearing NVRAM

During the flashing process, the coordinator's memory (NVMEM) may contain arbitrary data, which may in some cases prevent NVMEM recovery from the backup.

=== "Zigbee2MQTT"
    The coordinator's memory is cleared by the `zStackEraseAllNvMem.js` script, which is usually located in this directory:
	```
	/opt/zigbee2mqtt/scripts 
	```
	The command line will look something like this:
	```
	node zStackEraseAllNvMem.js /dev/ttyUSB0
	```
	```
	node zStackEraseAllNvMem.js socket://ip_or_localdns_name:6638
	```
=== "Zigpy-ZNP"

	Download and install zigpy-znp: 
	```
	pip install zigpy-znp
	```
	Erase your device's NVRAM entries to fully reset it:
	```
	python -m zigpy_znp.tools.nvram_reset /dev/serial/by-id/your-radio
	```
	```
	python -m zigpy_znp.tools.nvram_reset socket://ip_or_localdns_name:6638
	```
	Some warnings are normal, as not all entries will be present in every device.

!!! info
	At the end of the flashing, you may need to unplug-plug your device or press RST.

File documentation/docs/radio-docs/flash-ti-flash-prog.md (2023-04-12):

---
title: Smart RF Flash Programmer 2
description: Flashing Zigbee Modules using Smart RF Flash Programmer 2
hide:
  - tags
tags:
  - flashing
  - bsl
  - erase
---

# Flash Firmware using TI SmartRF Flash Programmer v2

Go to [TI's Website](https://www.ti.com/tool/FLASH-PROGRAMMER)and download SmartRF Flash Programmer v2.

Make sure you download and install FLASH-PROGRAMMER-2.

## Determine the USB port

Plug your device in and ensure that device is recognised by your OS:

On windows, use this in a Powershell or go to Device Manager

	$comports = Get-WMIObject Win32_SerialPort; $comports | Get-PnpDeviceProperty -InstanceId {$_.pnpdeviceid} -Keyname DEVPKEY_Device_BusReportedDeviceDesc | ForEach-Object { foreach($comport in $comports) { if ($comport.pnpdeviceid -eq $_.instanceid) { new-object psobject -property  @{COMPORT = $comport.deviceid; 'Device-Name' = $_.data} } } }

The drivers for CH340 should be automatically be picked up,check under "Ports (COM & LPT)" in Device Manager:

BSL Button
	
If you need to install the drivers manually, go [HERE](http://www.wch.cn/downloads/CH341SER_ZIP.html)for official drivers.
	
!!! TIP
        Double-check by undocking the device again.

## Put your stick in BSL mode

Please follow the following instructions to put your stick in BSL mode:

  - Unplug your stick from the host
  - Press the `BSL` pushbutton and keep holding while plugging the device back into the host:

BSL Button BSL Button

  - Give it a few seconds for the device to settle and set up and release the BSL button
  - Your stick should now be in ROM bootloader mode

<ins>It's very important that you press and hold the BSL button **before** plugging it in to the host and release it **after a few seconds**. If you don't follow this, your stick will not enter BSL mode and flashing will fail.</ins>

## Select correct device

We need to tell SmartRF Flash Programmer v2 what target device we have on our stick. Select "CC2652P":

Select correct chip

## Select firmware file and flash device

With the correct serial port chosen and target device selected, click "Browse" and select the firmware you want to flash (see [here](/radio-docs/quick-start/#step-2-download-the-correct-firmware-for-your-device) for help on choosing firmware).

!!! warning
	It is crucial that you download the correct firmware for your stick as using the wrong firmware will disable the BSL and you will need an external debugger / programmer to flash your stick again.</p>

With the correct firmware chosen, make sure that "Erase", "Program" and "Verify" are all chosen under "Actions" and press the blue button to start flashing:

Flash windows

If all goes to plan, after a few seconds you should see a green bar confirming that the flashing operating suceeded:

Flash succesful

You can now proceed to configuring your software of choice see [HERE](/radio-docs/z2m-zha/).

If your stick is not in BSL mode or you have not chosen the correct serial port, you will get the following error message:

Flash failed

Unplug your stick and try again according the instructions.

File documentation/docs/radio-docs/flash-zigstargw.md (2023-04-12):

---
title: Flash ZigStar LAN Gateway
description: Flashing Procedure for ZigStar LAN/POE Gateway 
hide:
  - tags
tags:
  - esp32
  - firmware
  - WT32-ETH01
  - TTGO
  - LAN
  - gateway
---

# Flash ZigStar LAN Gateway Firmware

## Requirements

- [NodeMCU PyFlasher](https://github.com/marcelstoer/nodemcu-pyflasher/releases/latest/download/NodeMCU-PyFlasher.exe)
- [ZigStarGW-FW](https://github.com/xyzroe/ZigStarGW-FW/releases/latest/)[^1]
- USB-C Type Cable

## Flash firmware

### Step 1: Activate Flash Mode

To enable flash mode on ESP32, BOOT button/switch should be pressed before you plug in your USB cable.<br>
Press and HOLD for 5 seconds after you plugged in your USB cable to PC.

*Be sure DIP switch is in ESP Mode( or jumpers are not soldered)

Press&Hold-BOOT

### Step 2: Firmware flashing

Start the previously loaded NodeMCU pyFlasher Tool, and select the identified serial port from the list, as well as the downloaded firmware file.

<div class="swiper stick">
      <div class="swiper-wrapper">
		<div class="swiper-slide">
          ”NodeMCU-Step1”
        </div>
        <div class="swiper-slide">
          ”NodeMCU-Step2”
        </div>
        <div class="swiper-slide">
          ”NodeMCU-Step3”
        </div>
      </div>

    </div>

???+ done
	
	At this point you are up and running.<br>
	Access your device by IP or hostname using your browser.

???+ note

    Flashing is required only once if you assembly device yourself or move from ESP-HOME.
	Use [ZigStarGW_vx.x.x.full.bin](https://github.com/xyzroe/ZigStarGW-FW/releases/latest/)for [NodeMCU PyFlasher](https://github.com/marcelstoer/nodemcu-pyflasher/releases/latest/download/NodeMCU-PyFlasher.exe)

### Step 3: ZigBee Firmware Update ( Optional )

In case you want to update/install your Zigbee Firmware, follow [ZigStar MultiTool Instructions](/radio-docs/zigstar-multi-tool/)

[^1]: Download [ZigStarGW_vx.x.x.full.bin](https://github.com/xyzroe/ZigStarGW-FW/releases/latest/)if you are using [NodeMCU PyFlasher](https://github.com/marcelstoer/nodemcu-pyflasher/releases/latest/download/NodeMCU-PyFlasher.exe)
[^2]: Will be downloaded .bin , is specially for OTA update.

## Update your firmware

To update your existing firmware[^2] just go to your browser and access your device by IP or hostname.

<div class="swiper stick">
      <div class="swiper-wrapper">
		<div class="swiper-slide">
          ”Acces
        </div>
        <div class="swiper-slide">
          ”Download
        </div>
		<div class="swiper-slide">
          ”Update
        </div>
      </div>

    </div>

???+ done
	
	Congratulations, you are on last firmware.[^2]

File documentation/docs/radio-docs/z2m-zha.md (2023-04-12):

---
title: Configuration Z2M/ZHA
description: Zigbee2MQTT and ZHA Setup Documentation ZigStar
hide:
  - tags
tags:
  - Z2M
  - ZHA
  - Zigbee2MQTT
  - Home Assistant
---

# Choose your side

[Zigbee2MQTT](https://www.zigbee2mqtt.io/) has support for TI CC2652P/CC2652RB chips used on this boards.<br>
ZHA Supports both TI and SiLabs chips. 

## First Steps

Choose your device instructions:

=== "USB Stick v4"

	1. Power on your USB Stick
	2. Make sure that the USB-serial bridge drivers are installed and your device is recognised (instructions [here](/radio-docs/flash-cc-bsl/#determine-the-usb-port-ip-address)).
	3. Configure your software to access the device.	
		
	=== "Zigbee2MQTT"
	
		Currently only TI Chips are supported by Z2M( CC2652P/CC2652RB ).
		
		With the correct serial port identified, edit your Zigbee2MQTT `configuration.yaml` :
		```
		serial:
			port: /dev/ttyUSB0  (change this if it is different on your machine)
		```
	
	=== "ZHA"
		3.1. Add the ZHA Integration via the Add Integrations option:
	
		ZHA-0

		3.2. From dropdown menu select your stick:
	
		ZHA-1
	
		3.3. Choose the device path of USB Stick and wait for installation to complete.
		
		- In case the autodetection fails,a manual setup menu will be displayed.
	
		!!! info
			Enter <b>device path</b> and <b>Port Speed:115200</b> and Software Flow Control leave empty.
	
		ZHA-3
		
		!!! info
			If ZHA is unable to connect to the USB adapter then try re-plugging in the USB adapter or try moving it to another USB-port.
	
=== "LAN/PoE Gateway"
	
	1. Connect the gateway to a ethernet cable which has access to your local network.
	2. Power on the gateway with a Type C cable.
	3. Determine the device's ip address,if your local network supports .local mdns addresses, the devices can be reached that way:
		```
		zigstargw.local
		```
		or by static ip.
	
		!!! info
			If its used Static IP Address - be sure it is reserved in your router,so will not change after reboot.

	4. Configure your software to access the device.<br>	
		
	=== "Zigbee2MQTT"
	
		Currently only TI Chips are supported by Z2M( CC2652P/CC2652RB ).
		
		With the correct IP or hostname identified, edit your Zigbee2MQTT `configuration.yaml`:
		```
		serial:
			port: 'tcp://ip_or_hostname:6638'
		```

	=== "ZHA"
		4.1. Add the ZHA Integration via the Add Integrations option:
	
		ZHA-0

		4.2. From dropdown menu select Manual:
	
		ZHA-1
	
		4.3. Select the Radio type for your chip:
	
		ZHA-2
	
		!!! info
			For TI based gateways select ZNP<br>
			For SiLabs based gateways select EZSP
		
		4.4. Enter <b>socket://ip_or_hostname:6638</b> and <b>Port Speed:115200</b> and Software Flow Control leave empty.
	
		ZHA-3
	
## Troubleshooting

### Zigbee2MQTT: Error Network Commissioning Timeout (panID or extendedPanID already exists nearby)
This error is discussed in these two threads: [first](https://github.com/Koenkk/zigbee2mqtt/issues/10858) and [second](https://github.com/tube0013/tube_gateways/issues/95).  
According to the first thread, the most possible issue cause this error is: `zigbee2mqtt will always use the same, default extendedPanId unless you set it to something else in the config file`
```yaml
advanced:
  pan_id: GENERATE
  ext_pan_id: [0x01, 0x02, 0x03, 0x04, 0x05, 0x06, 0x07, 0x08]
  network_key: GENERATE
```
According to the second thread, the users propose to start without antennas or routers nearby: `Try unscrewing the antenna during startup or unplug any near by routers temporarily.`

Try to do abovementioned as well as start ZHA just to test your device:

1. Go to Home Assistant
2. Click `Settings`
3. Go to `Devices & Services`
4. Click `Add integration` (right bottom corner)
5. Find «Zigbee Home Automation», click on it;
6. Between two options «Add Zigbee device» and «Zigbee Home Automation» choose `Zigbee Home Automation`;
7. Select serial port window - `Enter manually`
8. Radio type window - `ZNP = Texas Instruments Z-Stack ZNP … `
9. Serial port settings window:
	- Serial device path: « socket://192.168.1.105:6638 », where 192.168.1.105 is IP address of your ZigStar Adapter;
	- port speed left by default 115200;
	- data flow control undefined (it does not matter for LAN adapters)
10. Press `Submit`.
11. Network formation window - `Erase network settings and form a new network`
12. Wait for Zigbee network and try to add some Zigbee end-device (e.g. sensor etc)

If ZHA starts - means that the problem in communication between Zigbee2MQTT and Z-Stack firmware, flashed to the adapter. To solve it - try steps above ZHA part.

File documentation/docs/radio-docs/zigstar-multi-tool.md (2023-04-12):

---
title: ZigStar Multi Tool
description: Instructions for ZigStar Multi Tool
hide:
  - tags
tags:
  - cc2538-bsl
  - flashing
  - bsl
  - erase
  - nvram
  - multi tool
---

# ZigStar Multi Tool

[ZigStar Multi Tool](https://github.com/xyzroe/ZigStarGW-MT)is GUI tool designed for easy work with ZigStar LAN GW and USB Stick and packed into single executable file.<br>
You can get started without installing Python and the required modules - just download and open.

*All ZigStar boards( LAN or USB) are supported by Multi Tool.(now also supports sticks, regardless of the manufacturer) 

[Download](https://github.com/xyzroe/ZigStarGW-MT/releases/){ .md-button , target=_blank}

## Features
- Read / Write / Erase NVRAM memory of Zigbee module
- Write / Verify / Erase firmware of Zigbee module
- Backdoor Serial Loader turns on automatically
- Manual restart of  Zigbee module or ESP32 is available
- Comaptible with OS X, Windows and Ubuntu
  
## Screenshots

<table>
<tr> 
<td width="50%">

<b>Windows</b>

</td>
<td width="50%">

<b>OS X</b>

</td>
</tr>
</table>

## Instructions:

### Identify Port

On main ap window press refresh button in order to identify your USB Stick port or LAN GW address.<br>
and choose your device from drop-down list:

ZigStar GW Multi Tool

### Firmware update

1. Choose your .hex file from you PC
2. Choose required options,usually is Erase,Write and Verify
3. Press Start for flashing process(not all USB dongle entering BSL mode,depending on manufacturer)*

Multi Tool FLASH

*All ZigStar Sticks and LAN GW are automaticaly entering BSL mode

### NVRAM Tools

When is coming to firmware bugs,problems with zigbee network NVRAM tool come at help.

1. Backup your ZigBee NVRAM for future use or restore to another Dongle/LAN Coordinator
2. Write you existing backup back to Dongle/LAN Coordinator
3. Erase you Dongle/LAN Coordinator NVRAM for a fresh install

Multi Tool NVRAM

## Video description

*English subtitles available

<iframe width="560" height="315" src="https://www.youtube.com/embed/o8u1tMEa9lA" title="YouTube video player" frameborder="0" allow="accelerometer; autoplay; clipboard-write; encrypted-media; gyroscope; picture-in-picture" allowfullscreen></iframe>

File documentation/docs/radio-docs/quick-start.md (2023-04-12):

---
title: Quick Start
description: Quick Start for ZigStar Projects
hide:
  - tags
tags:
  - Quickstart
  - ZHA
  - Zigbee2MQTT
  - Z2M
  - Home Assistant
  - HA
---

# Quick Start for ZigStar Projects

This page provides a overview of what you'll need to do to set up your USB/LAN Coordinator to be used with the great collection of open-source home automation software, [Z2M(Zigbee2MQTT)](https://www.zigbee2mqtt.io/)or [ZHA](https://www.home-assistant.io/integrations/zha/)

## 1.Plug your device in

First step in getting your coordinator working is to ensure that your computer, server or Raspberry Pi recognises the device plugged in (specifically, the "USB to Serial Converter" chip) and installs the drivers needed. 

For network devices that they are reachable by network, using IP address or hostname.

Each coordinator is compatible by default with [Z2M(Zigbee2MQTT)](https://www.zigbee2mqtt.io/)and [ZHA](https://www.home-assistant.io/integrations/zha/)

## 2.Download firmware

If you are using correct firmware,you dont need an external debugger/programmer as the chips used have a built-in bootloader (BSL)! 

There are two ways you can use your device, either as a **coordinator** or a **router**.

=== "**Coordinator**"
	This is the firmware you need if you're going to be using your coordinator with [Z2M(Zigbee2MQTT)](https://www.zigbee2mqtt.io/), [ZHA(Home Assistant)](https://www.home-assistant.io/integrations/zha/)or any other ZNP-firmware-compliant software.
     
	| RF-STAR RF-BM-2652P2 | Ebyte E72-2G4M20S1E
	|----------------------|--------------------|
	| [CC1352P2_CC2652P_launchpad_*.zip](https://github.com/Koenkk/Z-Stack-firmware/tree/master/coordinator/Z-Stack_3.x.0/bin)| [CC1352P2_CC2652P_other_*.zip](https://github.com/Koenkk/Z-Stack-firmware/tree/master/coordinator/Z-Stack_3.x.0/bin)|

	!!! info
		CC1352P2_CC2652P_launchpad_*.zip - RF-BM-2652P1/P2 modules<br>
		CC1352P2_CC2652P_other_*.zip - E72-2G4M20S1E module
		
=== "**Router**"
	 If you're looking to extend the range of your network, flash your coordinator with the router firmware and plug it into a power source somewhere central in your home for stand-alone operation. Refer to the [README](https://github.com/Koenkk/Z-Stack-firmware/blob/master/router/Z-Stack_3.x.0/bin/README.md)for setup instructions.
	
	| RF-STAR RF-BM-2652P2 | Ebyte E72-2G4M20S1E
	|----------------------|--------------------|
	| [CC1352P2_CC2652P_launchpad_router_*.zip](https://github.com/Koenkk/Z-Stack-firmware/tree/master/coordinator/Z-Stack_3.x.0/bin)| [CC1352P2_CC2652P_other_router_*.zip](https://github.com/Koenkk/Z-Stack-firmware/tree/master/coordinator/Z-Stack_3.x.0/bin)|

	!!! info
		CC1352P2_CC2652P_launchpad_router_*.zip - RF-BM-2652P1/P2 modules<br>
		CC1352P2_CC2652P_other_router*.zip - E72-2G4M20S1E module

!!! danger
	It is crucial that you download the correct firmware for your coordinator as using the wrong firmware will disable the BSL and you will need an external debugger / programmer to flash your coordinator again.</p>
		
## 3.Flash the firmware

With the firmware of your choice downloaded and unziped, you should end up with a single .hex file that will need to be flashed to your coordinator. Three options for that:

  - The beginner friendly option: [ZigStar Multi Tool](/radio-docs/zigstar-multi-tool/#zigstar-multi-tool)
  - Windows-only option: [Flash firmware using TI's Flash Programmer 2](/radio-docs/flash-ti-flash-prog/)
  - Cross-platform option using Python: [Flash firmware using cc2538-bsl](/radio-docs/flash-cc-bsl/)

## 4.Setup Zigbee2MQTT or ZHA

Configure your choice of software so that it can talk to your coordinator.
For instruction go [HERE](/radio-docs/z2m-zha/)

## 5.Have fun!

With your coordinator flashed and the software of your choice configured,  you can start to pair your devices and start exploring the world of open-source Home Automation!<br>
A significant amount of effort goes to developing, maintaining and supporting the open source home automation ecosystem so if you can, please consider donating to the great software projects that are mentioned in these pages.<br>

A portion of each sale of ZigStar radio boards will be donated to [@Koenkk](https://github.com/Koenkk/) to support his work on [Zigbee2mqtt](https://github.com/Koenkk/zigbee2mqtt).

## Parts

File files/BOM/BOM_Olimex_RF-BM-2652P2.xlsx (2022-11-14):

No. | Quantity | Comment | Designator | Footprint | Value | Manufacturer Part | Manufacturer | Supplier Part | Supplier
1 | 1 | 22uF | C1 | CAP-SMD_L3.5-W2.8-R-RD | 22uF | CA45-B-16V-22uF-K | CEC(振华新云) | C129568 | LCSC
2 | 1 | 10uF | C2 | CAP-SMD_L3.5-W2.8-R-RD | 10uF | TAJB106K020RNJ | Kyocera AVX | C8017 | LCSC
3 | 3 | 100nF | C3,C4,C5 | C0805 | 100nF | CC0805KRX7R9BB104 | YAGEO(国巨) | C49678 | LCSC
4 | 1 | SS34 | D1 | DO-214AC_L4.3-W2.7-LS5.3-RD |  | SS34 | MDD | C8678 | LCSC
5 | 1 | KH-2.54PH180-1X3P-L11.5 | H1 | HDR-TH_3P-P2.54-V-M |  | KH-2.54PH180-1X3P-L11.5 | kinghelm(金航标) | C2932698 | LCSC
6 | 1 | DEBUG-TI | JTAG1 | SDIP-D-7_2.54 |  | MTP125-1108S1 | MINTRON | C358689 | LCSC
7 | 1 | G | L1 | LED0805-RD |  | 0805G (Green) | KENTO | C2297 | LCSC
8 | 1 | R | L2 | LED0805-RD |  | FC-2012HRK-620D | NATIONSTAR | C84256 | LCSC
9 | 1 | 直排针2X4P 2.54mm | P1 | HDR-TH_8P-P2.54-V-M-R2-C4-S2.54 |  | 直排针2X4P 2.54mm | BOOMELE(博穆精密) | C58363 | LCSC
10 | 2 | SS8050_C2150 | Q1,Q2 | SOT-23-3_L2.9-W1.3-P1.90-LS2.4-BR |  | SS8050 | CJ | C2150 | LCSC
11 | 2 | 5.1kΩ | R1,R2 | R0805 | 5.1kΩ | 0805W8F5101T5E | UNI-ROYAL(厚声) | C27834 | LCSC
12 | 2 | 0805W8F220JT5E | R3,R4 | R0805 |  | 0805W8F220JT5E | UNI-ROYAL(厚声) | C17561 | LCSC
13 | 2 | 1kΩ | R5,R6 | R0805 | 1kΩ | 0805W8F1001T5E | UNI-ROYAL(厚声) | C17513 | LCSC
14 | 1 | 4.7kΩ | R7 | R1206 | 4.7kΩ | 1206W4F4701T5E | UNI-ROYAL(厚声) | C17936 | LCSC
15 | 2 | 10kΩ | R8,R9 | R0805 | 10kΩ | 0805W8F1002T5E | UNI-ROYAL(厚声) | C17414 | LCSC
16 | 1 | BWSMA-KE-P001 | RF1 | SMA-SMD_BWSMA-KE-P001 |  | BWSMA-KE-P001 | BAT WIRELESS | C496550 | LCSC
17 | 1 | BSL | SW1 | SW-SMD_L3.9-W3.0-P4.45 |  | SKRKAEE020 | ALPS | C115357 | LCSC
18 | 1 | RF-BM-2652P1-V2 | U1 | RF-BM-2652P1-V2 |  |  | RF-STAR |  | RF-STAR
19 | 1 | OLIMEX ESP32-POE | U2 | OLIMEX ESP32-POE |  |  |  |  | Olimex
20 | 1 | AMS1117-3.3 | U3 | SOT-223-3_L6.5-W3.4-P2.30-LS7.0-BR |  | AMS1117-3.3 | AMS | C6186 | LCSC
21 | 1 | CH340B | U4 | SOIC-16_L9.9-W3.9-P1.27-LS6.0-BL |  | CH340B | WCH | C81010 | LCSC
22 | 1 | DS18B20 | U5 | TO-92-3_L4.9-W3.7-P1.27-L |  | DS18B20 | Youtai Semiconductor Co., Ltd. | C376006 | LCSC
23 | 1 | TYPE-C-31-M-12 | USBC1 | USB-C_SMD-TYPE-C-31-M-12 |  | TYPE-C-31-M-12 | Rectangular Connectors - Contacts | C165948 | LCSC

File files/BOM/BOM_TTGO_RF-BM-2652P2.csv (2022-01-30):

ID | Name | Designator | Footprint | Quantity | Manufacturer Part | Manufacturer | Supplier | Supplier Part | Price
1 | 100nF | C1,C4,C5 | C0805 | 3 | CL21B104KCFNNNE | SAMSUNG | LCSC | C28233 | 0.009
2 | 10uF | C2 | CAP-SMD_L3.2-W2.8 | 1 | TAJB106K016RNJ | AVX | LCSC | C7193 | 0.161
3 | 22uF | C3 | CAP-SMD_L3.5-W2.8-R-RD | 1 | TAJB226K016RNJ | AVX | LCSC | C8020 | 0.164
4 | A2005HWV-6P | CN1 | HDR-TH_6P-P2.00-V-F | 1 | A2005HWV-6P | Changjiang Connectors | LCSC | C225284 | 0.187
5 | I2C | CN3 | HDR-4X1/2.54 | 1 | Header-Female-2.54_1x4 | ReliaPro | LCSC | C124413 | 0.117
6 | 210S-2*4P L=11.6MMGold-plated black | H1 | HDR-TH_8P-P2.54-V-M-R2-C4-S2.54 ZIG-ETH | 1 | 210S-2*4P L=11.6MMGold-plated black | Ckmtw | LCSC | C124386 | 0.059
7 | DEBUG-TI | JTAG2 | HDR-TH_7P-P2.54-V-M | 1 | PZ254V-11-07P | XFCN | LCSC | C492406 | 0.041
8 | G | L1 | LED0805-RD | 1 | 0805G (Green) | KENTO | LCSC | C2297
9 | R | L2 | LED0805-RD | 1 | FC-2012HRK-620D | NATIONSTAR | LCSC | C84256 | 0.013
10 | SS8050_C2150 | Q1,Q2 | SOT-23-3_L2.9-W1.3-P1.90-LS2.4-BR | 2 | SS8050 | CJ | LCSC | C2150 | 0.022
11 | 4.7K | R1 | R0805 | 1 | 0805W8F4701T5E | UniOhm | LCSC | C17673 | 0.003
12 | 1K | R2,R3 | R0805 | 2 | 0805W8F1001T5E | UniOhm | LCSC | C17513 | 0.002
13 | 5.1K | R4,R5 | R0805 | 2 | 0805W8F5101T5E | UniOhm | LCSC | C27834 | 0.002
14 | 10K | R6,R7 | R0805 | 2 | 0805W8F1002T5E | UniOhm | LCSC | C17414 | 0.002
15 | BWSMA-KE-P001 | RF1 | SMA-SMD_BWSMA-KE-P001 | 1 | BWSMA-KE-P001 | BAT WIRELESS | LCSC | C496550 | 0.525
16 | BSL | SW1 | SW-SMD_L3.9-W3.0-P4.45 | 1 | SKRKAEE020 | ALPS | LCSC | C115357 | 0.109
17 | Header-Female-2.54_2x8 | U1 | HDR-TH_16P-P2.54-V-F-R2-C8-S2.54-1 | 1 | 2.54mm,2×8Double female header | BOOMELE | LCSC | C30734 | 0.116
18 | AMS1117-3.3 | U2 | SOT-223-3_L6.5-W3.4-P2.30-LS7.0-BR | 1 | AMS1117-3.3 | AMS | LCSC | C6186 | 0.164
19 | CH340B | U3 | SOIC-16_L9.9-W3.9-P1.27-LS6.0-BL | 1 | CH340B | WCH | LCSC | C81010 | 1.385
20 | RF-BM-2652P1-V2 | U4 | RF-BM-2652P1-V2 | 1 |  | RF-STAR | RF-STAR
21 | E72-2G4M20S1E | U5 | E72-2G4M20S1E | 1 | E72-2G4M20S1E | EBYTE
22 | E72-2G4M05S1F | U6 | E72-2G4M05S1F | 1 | E72-2G4M05S1F | EBYTE | aliexpress | https://aliexpress.com/item/1005002603670450.html
23 | DS18B20 | U7 | TO-92-3_L4.9-W3.7-P1.27-L | 1 | DS18B20 | Youtai Semiconductor Co., Ltd. | LCSC | C376006 | 0.908
24 | TYPE-C-31-M-12 | USBC | USB-C_SMD-TYPE-C-31-M-12 | 1 | TYPE-C-31-M-12 | Rectangular Connectors - Contacts | LCSC | C165948 | 0.351

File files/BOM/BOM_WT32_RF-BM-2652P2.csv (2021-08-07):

ID | Name | Designator | Footprint | Manufacturer Part | Manufacturer | Supplier | Supplier Part | Price
13 | 10uF | C1 | CAP-SMD_L3.5-W2.8-R-RD | TAJB106K016RNJ | AVX | LCSC | C7193 | 0.173
14 | 100nF | C2,C4 | C0805 | CT41G-0805-2X1-50V-0.1uF-K(N) | TORCH | LCSC | C126469
15 | 22uF | C3 | CAP-SMD_L3.5-W2.8-R-RD | TAJB226K016RNJ | AVX | LCSC | C8020 | 0.175
7 | 0805 jUMPER | J1,J2 | JMP-2-NO-0603 | 0805 jUMPER
8 | 0805 jUMPER | J3 | JMP-2-NO-0402 | 0805 jUMPER
19 | R | L1 | LED0805-RD | FC-2012HRK-620D | NATIONSTAR | LCSC | C84256 | 0.012
20 | G | L2 | LED0805-RD | 0805G (Green) | KENTO | LCSC | C2297 | 0.016
12 | 10K | R1 | R0805 | 0805W8F1002T5E | UniOhm | LCSC | C17414 | 0.002
17 | 1K | R3,R2 | R0805 | RS-05K1001FT | FH | LCSC | C115316 | 0.002
10 | 5.1K | R4,R5 | R0805 | 0805W8F5101T5E | UniOhm | LCSC | C27834 | 0.002
11 | 22 | R6,R7 | R0805 | 0805W8F220JT5E | UniOhm | LCSC | C17561 | 0.002
2 | BWSMA-KE-P001 | RF1 | SMA-SMD_BWSMA-KE-P001 | BWSMA-KE-P001 | BAT WIRELESS | LCSC | C496550 | 0.405
3 | BOOT | SW1 | SW-SMD_L3.9-W3.0-P4.45 | SKRKAEE020 | ALPS | LCSC | C115357 | 0.099
5 | BSL | SW2 | SW-SMD_L3.9-W3.0-P4.45 | SKRKAEE020 | ALPS | LCSC | C115357 | 0.099
4 | RST | SW3 | SW-SMD_L3.9-W3.0-P4.45 | SKRKAEE020 | ALPS | LCSC | C115357 | 0.099
1 | RF-BM-2652P1-V2 | U1 | RF-BM-2652P1-V2 |  | RF-STAR | RF-STAR
16 | WT32-ETH01 MODULE | U2 | WT32-ETH01-M MODULE | WT32-ETH01 | Wireless-Tag |  | WT32-ETH01
18 | CH340C | U3 | SOP-16_L10.0-W3.9-P1.27-LS6.0-BL | CH340C | WCH | LCSC | C84681 | 0.48
6 | AMS1117 | U4 | SOT-223_L6.5-W3.5-P2.30-LS7.0-BR | AMS1117-3.3 | SK | LCSC | C165482 | 0.054
9 | TYPE-C-31-M-12 | USBC1 | USB-C_SMD-TYPE-C-31-M-12 | TYPE-C-31-M-12 | Rectangular Connectors - Contacts | LCSC | C165948 | 0.29

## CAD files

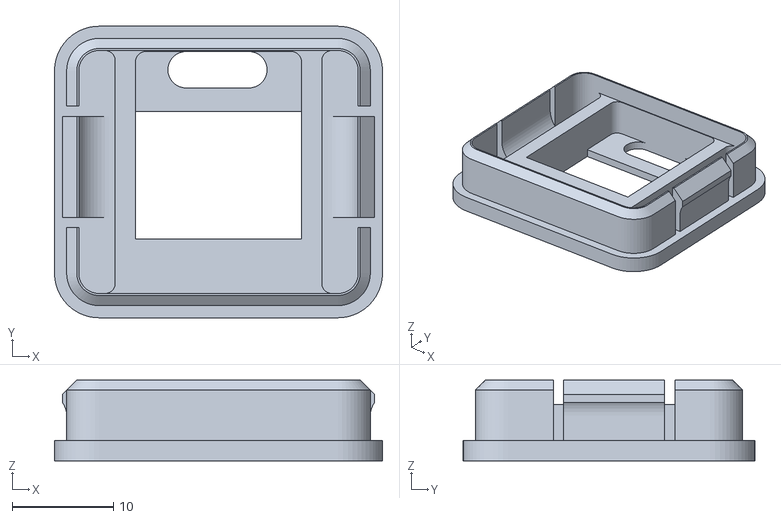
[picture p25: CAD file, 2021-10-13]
files/STL/WT32-ETH01_LAN_Gateway/Cover 1.6mm PCB by Alex.F_self_assembly.stl
32.4 x 28.8 x 8.00

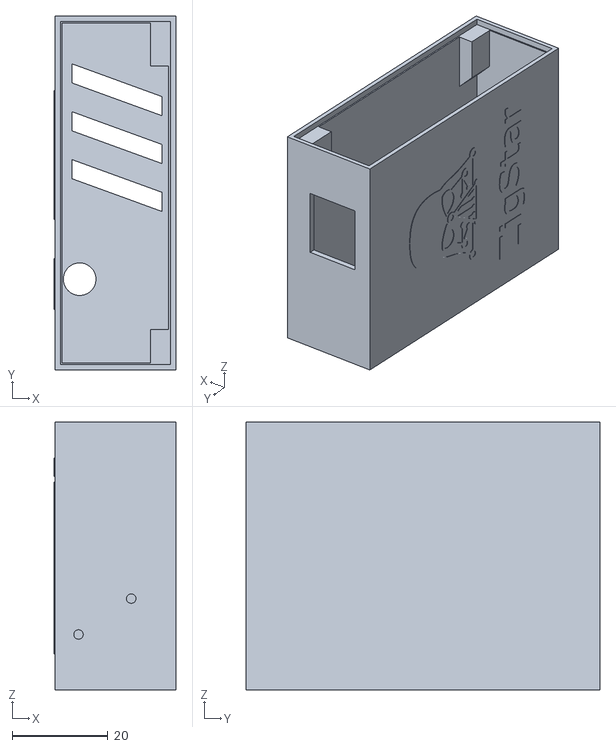
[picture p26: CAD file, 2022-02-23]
files/STL/LilyZig_POE_Gateway/TTGO_case_v2.stl
25.4 x 73.9 x 55.9

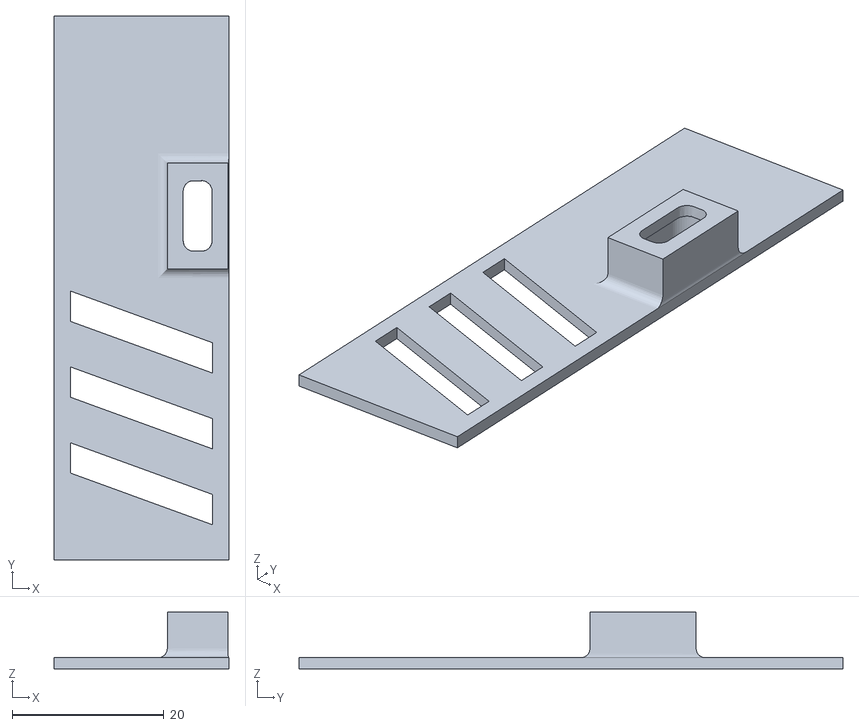
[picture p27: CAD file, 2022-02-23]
files/STL/LilyZig_POE_Gateway/TTGO_cover_v2.stl
23.0 x 71.7 x 7.47

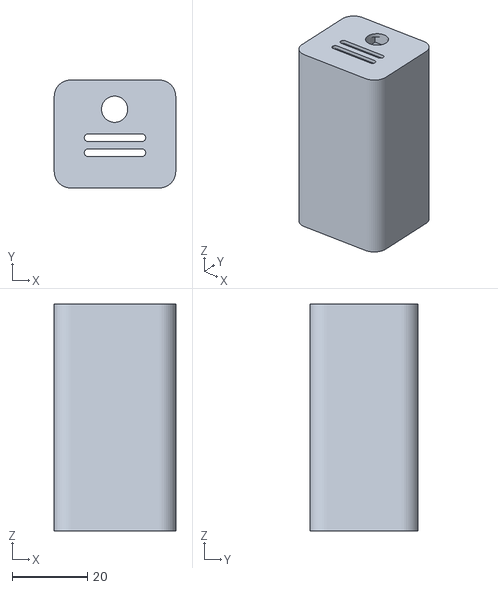
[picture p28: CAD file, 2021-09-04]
files/STL/WT32-ETH01_LAN_Gateway/Body by Alex.F.stl
32.4 x 28.8 x 60.5

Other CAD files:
files/STL/WT32-ETH01_LAN_Gateway/Cover 1.2mm PCB by Alex.F_sales.stl

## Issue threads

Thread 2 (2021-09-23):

[REQUEST] Zeroconf support to ZigStar LAN Gateway for Home Assistant ZHA network discovery

Hedda, 2021-09-23:
Please consider adding Zeroconf DNS TXT Records parameters in firmware for automatic ZHA network discovery but only enable it when running in "Zigbee Home Automation Mode".

Home Assistant OS (formerly HASSIO) support automatic network scanning and “Service Discovery” via Zeroconf and when a whitelisted Zigbee serial gateway is discovered it can pass along that to a domain like the ZHA integration component in Home Assistant.

For more context about this Zigbee gateway “Service Discovery” via Zeroconf for the ZHA integration in Home Assistant, pease see:

https://community.home-assistant.io/t/zha-automatic-discovery-of-zigbee-coordinator-bridges-gateways-ethernet-wifi-network-devices-that-support-zeroconf-or-ssdp/2933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

and

https://developers.home-assistant.io/docs/creating_integration_manifest/#zeroconf

FYI, there is already a working proof-of-concept this is now supported by Tube's Zigbee gateways (based on ESPHome firmware):

https://www.home-assistant.io/integrations/zha#discovery-via-usb-or-zeroconf

https://github.com/tube0013/tube_gateways

Once support for Zeroconf has been added to the firmware you also need the firmware to provide DNS TXT records for passing along setting parameters to integration config flows.

You first need to add Zeroconf service and give it name and as well as adding information about protocol (tcp) and port (????), etc.

Then DNS TXT records is used to pass along recommended settings parameters config flow to Home Assistant's ZHA integration:

```
version=1.0
radio_type=ezsp
baud_rate=value
data_flow_control=software
```

I believe that is advertised for Zeroconf config in this format or similar:
```
zha_ezsp_zeroconf  _ezsp._tcp  local
   hostname = [zha_ezsp_zeroconf.local]
   port = [8080]
   protocol = [tcp]
   service = tubes_zb_gw
   txt = ["version=1.0"]
   txt = ["radio_type=ezsp"]
   txt = ["baud_rate=value"]
   txt = ["data_flow_control=software"]
```
(use e.g. avahi-browse -r -a to see this)

As can see, you will need one DNS TXT Record for each attribute and value that is to be passed along to HA's ZHA integration.

Zeroconf DNS TXT records could also be used to pass along info about hostname, versions, location, MAC address, and more, etc..

http://www.zeroconf.org/Rendezvous/txtrecords.html

https://en.wikipedia.org/wiki/Zero-configuration_networking#DNS-based_service_discovery

https://en.wikipedia.org/wiki/TXT_record

More information about idea of using DNS TXT records for passing along setting parameters in https://github.com/thegroove/esphome-zbbridge#1 and https://github.com/thegroove/esphome-zha-ezsp-zeroconf

In the end it is probably best to see actual example config for ESPHome as in Tube's Zigbee Gateway as that is the reference:

https://github.com/tube0013/tube_gateways/blob/main/V2_tube_zb_gw_cc2752p2/ESPHome/tube_zb_gw_cc2652p2v2.yml

```
zeroconf:
  - service: tubes_zb_gw
    protocol: tcp
    port: 6638
    txt:
      version: 1.0
      radio_type: znp
      baud_rate: 115200
      data_flow_control: software
```

Again, support for Tube's Zigbee Gateway was initially added to Home Aassistant core for ZHA support in https://github.com/home-assistant/core/pull/48420

As I believe to then whitelist Zeroconf for more gateways and/or radio types in HA's zeroconf as well as for ZHA need to do PR for:

https://github.com/home-assistant/core/blob/dev/homeassistant/generated/zeroconf.py

```
 "_esphomelib._tcp.local.": [
        {
            "domain": "zha",
            "name": "tube*"
        }
    ],
```

and

https://github.com/home-assistant/core/blob/dev/homeassistant/components/zha/manifest.json

```
"zeroconf": [
    {
      "type": "_esphomelib._tcp.local.",
      "name": "tube*"
    }
  ],
```
and

https://github.com/home-assistant/core/blob/dev/homeassistant/components/zha/config_flow.py

```
async def async_step_zeroconf(self, discovery_info: DiscoveryInfoType):
        """Handle zeroconf discovery."""
        # Hostname is format: livingroom.local.
        local_name = discovery_info["hostname"][:-1]
        node_name = local_name[: -len(".local")]
        host = discovery_info[CONF_HOST]
        device_path = f"socket://{host}:6638"

        if current_entry := await self.async_set_unique_id(node_name):
            self._abort_if_unique_id_configured(
                updates={
                    CONF_DEVICE: {
                        **current_entry.data.get(CONF_DEVICE, {}),
                        CONF_DEVICE_PATH: device_path,
                    },
                }
            )

        # Check if already configured
        if self._async_current_entries():
            return self.async_abort(reason="single_instance_allowed")

        self.context["title_placeholders"] = {
            CONF_NAME: node_name,
        }

        self._device_path = device_path
        self._radio_type = (
            RadioType.ezsp.name if "efr32" in local_name else RadioType.znp.name
        )

```

mercenaruss, 2021-10-11:
Work is done on this, but having small trouble submitting this to HA Repo.

Hedda, 2021-10-18:
@mercenaruss Sorry for the delay, I have now posted a reply to https://community.home-assistant.io/t/zha-automatic-network-discovery-of-zigbee-coordinator-bridges-gateways-ethernet-wifi-network-adapters-that-support-zeroconf/293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

If your Zeroconf and DNS TXT Records if correct then think you should only need to extend code in these two source files:

https://github.com/home-assistant/core/blob/dev/homeassistant/generated/zeroconf.py

https://github.com/home-assistant/core/blob/dev/homeassistant/components/zha/manifest.json

The DNS server in your network router of course needs to support/enable mDNS (multicast DNS) so .local names can be used.

Hedda, 2022-02-03:
FYI, Zero-configuration networking (zeroconf) looks to have been changed and improved in the Home Assistant 2022.02 release:

https://github.com/home-assistant/core/pull/62133

https://www.home-assistant.io/integrations/zeroconf/

This change is only a concern for custom integration developers.

Currently zeroconf matching only allows matching the `macaddress`, `model`, and `manufacturer` properties along with the name from the ZeroconfServiceInfo.

Since properties are arbitrarily defined by the zeroconf service, the list of named properties has grown over time.

Matching now allows for any arbitrarily defined property. All property matches must be lowercase, wildcards are supported

The top level keys `model`, `manufacturer`, and `macaddress` are now deprecated from components `manifest.json` file and should be moved into a `properties` dict.

For example:

```
-    {"type":"_airplay._tcp.local.","model":"appletv*"}
+    {"type":"_airplay._tcp.local.","properties":{"model":"appletv*"}}
```

Hedda, 2022-02-06:
By the way, Home Assistant founders/leads now explicitly said this year they will prioritize focus on features like these types:

https://www.home-assistant.io/blog/2022/01/19/streamlining-experiences/

Check out this video at around 11 min 55 sec in where talk about that focus point about making it easier to get started, etc.

https://www.youtube.com/watch?v=t_2D_KoFIfU&t=710s

Hopefully, it should be a greater chance of getting more help from other Home Assistant developers with this if ask them.

Hedda, 2022-02-06:
FYI, PR https://github.com/home-assistant/core/pull/58224 for Home Assistant core has been closed since I cannot test it myself to confirm working or not.

It would be more than welcomed if anyone (who owns a ZigStar LAN Gateway) could take over to get zeroconf discovery in ZHA.

https://www.home-assistant.io/integrations/zha#discovery-via-usb-or-zeroconf

Again, other than Tube's Zigbee Gateways you can also checkout syssi's and thegroove's implementations as proof-of-concept:

https://github.com/syssi/esphome-zb-gw03

https://github.com/thegroove/esphome-zeroconf

https://github.com/thegroove/esphome-zha-ezsp-zeroconf

Hedda, 2022-03-30:
FYI, for reference, noticed that fairecasoimeme is working on a PR for Home Assistant which will add ZiGate discovery support:

https://github.com/home-assistant/core/pull/68577

"Add ZiGate device on automatic integration USB and ZEROCONF"

https://www.home-assistant.io/integrations/zha#discovery-via-usb-or-zeroconf

That will add automatic ZeroConf (MDNS) discovery of ZiGate Ethernet Gateway (not WiFi Gateway) + ZiGate USB adapters.

Hedda, 2022-05-10:
> FYI, for reference, noticed that fairecasoimeme from ZiGate is working on PR for Home Assistant to add ZiGate discovery support:
>
> See -> [home-assistant/core#68577](https://github.com/home-assistant/core/pull/68577) ("**_Add ZiGate device on automatic integration USB and ZEROCONF_**")

FYI, PR for ZiGate's Zeroconf been merged in Home Assistant core making it an example for adding more a little more readable:

https://github.com/home-assistant/core/pull/68577

https://github.com/home-assistant/core/blob/dev/homeassistant/components/zha/manifest.json#L85-L88

https://github.com/home-assistant/core/blob/dev/homeassistant/components/zha/config_flow.py#L198-L201

https://github.com/home-assistant/core/blob/dev/tests/components/zha/test_config_flow.py#L80-L107

https://github.com/home-assistant/core/blob/dev/homeassistant/generated/zeroconf.py#L384-L389

mercenaruss, 2022-09-11:
@Hedda Zeroconf tested & PR submitted.

Closed 2022-09-11.

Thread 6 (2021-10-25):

Test and list ZigStar Gateway compatibility with Jeedom Official Zigbee Plugin (which is based on zigpy)

Hedda, 2021-10-25:
Suggest you test and list ZigStar Gateway compatibility with Jeedom Official Zigbee Plugin (which is based on [zigpy](https://github.com/zigpy/zigpy) like [ZHA](https://www.home-assistant.io/integrations/zha)):

Jeedom Official Zigbee Plugin is based on [zigpy](https://github.com/zigpy/zigpy) (similar to the [ZHA integration component in Home Assistant](https://www.home-assistant.io/integrations/zha)) so should work:

https://blog.jeedom.com/5183-tout-ce-quil-faut-savoir-sur-le-plugin-officiel-zigbee/ <- Announcement is btw a great read!

https://market.jeedom.com/index.php?v=d&p=market_display&id=4050

https://doc.jeedom.com/en_US/plugins/automation%20protocol/zigbee/

"_The Zigbee plugin for Jeedom builds on the excellent work done around the open-source Zigpy library to offer general compatibility with different Zigbee hardware. It allows communication with the following Zigbee controllers_"

https://doc.jeedom.com/en_US/plugins/automation%20protocol/zigbee/changelog

https://community.jeedom.com/t/plugin-officiel-zigbee/58321

https://community.jeedom.com/t/plugin-zigbee-beta/40301

https://community.jeedom.com/t/plugin-zigbee-beta-blabla/53420

https://community.jeedom.com/tag/plugin-zigbee

https://compatibility.jeedom.com/index.php?v=d&p=home&search=&lang=en_US&protocol=Zigbee

Note that while the Jeedom Official Zigbee Plugin is open source but you need to buy it and install it to get the Python code for it.

Also note that the Jeedom Official Zigbee Plugin currently uses a fork of zigpy which already supports ZGP (Zigbee Green Power)

https://github.com/jeedom/zigpy

ZGP (Zigbee Green Power) has been submitted to upstream zigpy as a feature patch but that patch has not yet been merged yet.

Jeedom Logo

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

PS: I have no affiliations with Jeedom myself in any way, as I am just a fan of the zigpy project and all SW/HW projects related to it.

mercenaruss, 2022-09-11:
Jeedom list in their website and github,that they support all list of adapters from Z2M project.
Not necessary to list myself anywhere.

Closed 2022-09-11.

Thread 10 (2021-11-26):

Зависания WEB

lavrizone, 2021-11-26:
Заметил зависания web части при активированной настройке MQTT, если остановить аддон Z2M, то вебморда шлюза очень плохо откликается на действия, страница обновляется раз в примерно 10 секунд, стоит Z2M запустить, то всё налаживается.

mercenaruss, 2021-12-01:
@xyzroe Anything we can do about this?

mercenaruss, 2022-01-16:
@xyzroe any idea about this?

xyzroe, 2022-01-16:
I have no idea what is common between the mqtt configuration and the state of the z2m addon.

Web interface freezes are possible if there is no connection with the mqtt server. This is how the mqtt library works which is used in the firmware.

If someone has the opportunity to make issue in the correct [repository](https://github.com/xyzroe/ZigStarGW-FW/issues), this will help not to forget about it, at the time of working on the firmware.

Closed 2022-01-17.

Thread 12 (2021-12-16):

Test and verify Koenkk experimental firmware for CC2652P configurable up to 20 dBm TX power output

Hedda, 2021-12-16:
FYI, Koenkk has now uploaded an experimental firmware for CC2652P/CC1352P with a default set to 9 dBm (and a max of 20 dBm):

https://github.com/Koenkk/Z-Stack-firmware/issues/323

He mentions in https://github.com/Koenkk/zigbee2mqtt/issues/8885 that he does not have RF measurement equipment so cannot confirm RF output power.

Would be great if you can test and verify Koenkk experimental firmware for CC2652P configurable up to 20 dBm TX power output.

Hedda, 2021-12-20:
FYI, Koenkk has now released mentioned +20 dBM RF power output enabled version as "Z-Stack_3.x.0 20211217" in the develop branch and closed issues as confirmed working with improved LQI as result:

[https://github.com/Koenkk/Z-Stack-firmware/tree/develop/coordinator/Z-Stack_3.x.0/bin](https://github.com/Koenkk/Z-Stack-firmware/tree/develop/coordinator/Z-Stack_3.x.0/bin)

[https://github.com/Koenkk/Z-Stack-firmware/issues/323](https://github.com/Koenkk/Z-Stack-firmware/issues/323)

[https://github.com/Koenkk/zigbee2mqtt/issues/8885](https://github.com/Koenkk/zigbee2mqtt/issues/8885)

That firmware has during the weekend been confirmed working by several community members with up to +20 dBM RF power output enabled, (tested in both Zigbee2MQTT and ZHA), and according to Koenkk it has also been confirmed working by ITead's own Sonoff Zigbee engineer using RF analyzer as well, so I think later if and when proven stable we can expect this version to ship with future batches.

Note that any releases in the develop branch should still be considered experimental until proven stable and any bugs specifically verified related to this firmware version should be reported as new issues to:

[https://github.com/Koenkk/Z-Stack-firmware/issues](https://github.com/Koenkk/Z-Stack-firmware/issues)

Char-r, 2021-12-23:
I tested on a Zigstar-LAN and I am not getting great results. none of my IKEA E1746 extenders show as online and most devices fail to respond to pings at all.

I went back to a SONOFF USB3 and the routers were found straight away so seems to a compatibility issue somewhere.

Hedda, 2021-12-23:
Are you testing [Z-Stack_3.x.0 20211217 firmware](https://github.com/Koenkk/Z-Stack-firmware/tree/develop/coordinator/Z-Stack_3.x.0/bin) with Zigbee2MQTT or Home Assistant's ZHA?

It does not appear to fully work yet with zigpy-znp which ZHA uses, see -> https://github.com/zigpy/zigpy-znp/issues/119

Hedda, 2022-01-12:
FYI, 20211217 has now also been moved to "master" branch and should be considered stable as recommended version:

https://github.com/Koenkk/Z-Stack-firmware/tree/master/coordinator/Z-Stack_3.x.0/bin

By the way, the new "develop" branch got another also bug-fix:

https://github.com/Koenkk/Z-Stack-firmware/tree/develop/coordinator/Z-Stack_3.x.0/bin

https://github.com/Koenkk/Z-Stack-firmware/blob/develop/coordinator/Z-Stack_3.x.0/CHANGELOG.md

mercenaruss, 2022-01-16:
@Hedda hi,i'm back from vacation will start testing this firmware.
@Char-r Hi, please send me an email to see whats happening there. support@zig-star.com. Didnt get bad feedbacks,this will be one of the first,let see what is the problem.

mercenaruss, 2022-01-30:
Firmware was tested and is working properly.

Closed 2022-01-30.

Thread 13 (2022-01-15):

gerber version  1.2 ?

Symbol84, 2022-01-15:
Hello. What changes have been made, in the picture version 1.2., and the gerbers file version on the board is 1.0 ? Are there critical changes?

mercenaruss, 2022-01-16:
Hi,no any critical changes. Just some graphics changes.

Closed 2022-01-16.

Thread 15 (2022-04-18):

3.3V A short circuit     PCB problem C2 is incorrectly grounded in wiring and needs to be fixed. I also can't design the software, can't submit merge request

ahonxxx, 2022-04-18:
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

ahonxxx, 2022-04-18:
5V is also short-circuited
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

mercenaruss, 2022-04-20:
Hi,let me check and update today.
Thank you for pointing out this issues,nobody reported till now.

ahonxxx, 2022-04-22:
> 是否容易切断短路？我测试了还是不行，COM不能识别！

The copper sheet of the positive electrode of the capacitor needs to be cut off from top to bottom

65698888, 2022-04-22:
> 嗨，让我今天检查并更新。 感谢您指出这个问题，直到现在没有人报告。

> Hi,let me check and update today. Thank you for pointing out this issues,nobody reported till now.

Please inform  when updated, this is a very good project.

mercenaruss, 2022-05-08:
@ahonxxx @65698888 Problem solved,updated Gerbers are available.

Closed 2022-05-08.

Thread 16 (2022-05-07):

LilyZig: must 2.0mm UART be connected?

rea-ducks, 2022-05-07:
Hi there,

does LilyZigs 6 pin 2.0mm UART need to be connected to the TTGO T-Internet-POE?
Because I'm lacking the right connector, I don't have it connected and the Multi Tool only gets timeouts. So I need to sort out if I just have to find the right connector or look for the error elsewhere.

mercenaruss, 2022-05-08:
Hi,
yes,is required only for ESP firmware upload.
If you have USB-to-TTL then flash firmware for ESP and then everything else will be fine.

Closed 2022-05-08.

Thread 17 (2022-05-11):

[SUGGESTION] RTC (Real-Time-Clock) and a clock-battery + a buzzer and RGB LED to the PCB board?

Hedda, 2022-05-11:
Maybe consider adding an RTC (Real-Time-Clock) and a clock-battery + a buzzer and tri-color RGB LED or LEDs if it would not add to much cost to ZigStar gateways as products.

That way they could it would not only be a Zigbee Coordinator bridge or Zigbee Router but the ESPHome part could also serve multiple other purposes like for example an alarm-clock or doorbell-chime/buzzer with flashing lights in seperate colors to show/give status alerts for different things. See example these :

https://www.adafruit.com/product/5125

https://www.adafruit.com/product/5126

I read that the new “ITead SONOFF Zigbee Bridge Pro” in addition to having some kind of a "buzzer" so that it can be used as an alarm or a doorbell chime, and this new "Pro" variant also feature an onboard RTC (Real-Time-Clock) to keep time while offline-> https://github.com/arendst/Tasmota/discussions/14419

With both ESP32 and an RTC it would make it very suitable as a Zigbee2Tasmota gateway -> https://tasmota.github.io/docs/Zigbee/

Zigbee2Tasmota on an ESP32 based gateway RTC (Real-Time-Clock) and clock-battery could be used as a stand-alone offline gateway/hub to keep schemas and schedules for "Wake Up Alarm Clock" even when the internet goes down and it reboot, like when there is power blackout.

mercenaruss, 2022-09-12:
@Hedda unfortunately this is not the purpose for this devices.
I will think about this in future device releases.

Closed 2022-09-12.

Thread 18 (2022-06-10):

[REQUEST] OpenThread Border Router (OTBR) RCP and NCP firmware images for CC2652R based ZigStar Gateways/Adapters?

Hedda, 2022-06-10:
@mercenaruss  Can you please consider providing OpenThread Border Router (OTBR)  "RCP mode" firmware images well as "NCP mode" firmware images (with support for the OpenThread `spinel+hdlc+uart` protocol) and preferably using the latest SDK for this Texas Instruments CC2652 based gateway/adapter so that it will be compatible with the "OpenThread Border Router Add-on" that Home Assistant developer agners (Nabu Casa employee Stefan Agner) is currently developing? Check out:

https://github.com/home-assistant/addons-development/tree/master/openthread_border_router

https://github.com/openthread/ot-br-posix/

https://github.com/agners

https://community.home-assistant.io/u/agners/summary

https://groups.google.com/g/openthread-users/

 OTBR should be a "Thread Certified Component" Texas Instruments CC2652 based chips:

https://github.com/openthread/ot-cc13x2-cc26x2/blob/main/src/cc2652/README.md

https://github.com/openthread/ot-cc13x2-cc26x2

https://github.com/openthread/openthread/tree/main/examples/platforms

https://dev.ti.com/tirex/explore/node?node=APzU0zOtgnQIe0sFnHCfxg__BSEc4rl__LATEST

https://openthread.io/vendors/texas-instruments

https://www.threadgroup.org/What-is-Thread/Thread-Benefits#certifiedproducts

https://training.ti.com/thread-cc2652-cc1352

The main reason for this request is that an "RPC" firmware with OTBR (OpenThread Border Router) support will make your adapter will be compatible with upcoming Thread based "Matter" (Project CHIP / Connected Home over IP) devices if used in Home Assistant with their other add-ons for the that is also in development. This addon by agners requires that the radio hard a firmware in "RPC" mode instead of the no traditional "NCP" mode:

https://github.com/home-assistant/addons-development/tree/master/chip_controller_repl

https://github.com/home-assistant/addons-development/tree/master/chip_tool

https://github.com/project-chip/connectedhomeip

https://buildwithmatter.com

https://csa-iot.org/all-solutions/matter/

Also having optional OpenThread "NCP" border router firmware would allow users to alternatively use other existing OpenThread applications that use "NCP" mode instead of the newer "RPC" mode which require additional component running on the host. Ex:

https://github.com/openthread/wpantund

Note that so far agners has only worked with Silicon Labs based adapter with OpenThread "RPC" firmware for Thread based Matter (as well as ESP32-C3 based devkit for Matter over WiFi) and that is only because it is a Silabs EFR32MG21 chip based adapter that will ship inside the official Home Assistant Yellow (formerly Home Assistant Amber) hardware:

https://github.com/zigpy/zigpy/discussions/894

https://github.com/home-assistant/addons-development/tree/master/silabs-multiprotocol

https://www.home-assistant.io/blog/2021/09/13/home-assistant-yellow/

https://www.crowdsupply.com/nabu-casa/home-assistant-yellow

PS: By the way, you might be interested in the the "Matter" workshop that Home Assistant is holding on the 15th of June even if they are in that specific workshop will not use a Thread based controller or devices and instead use a WiFi (+ Bluetooth) based "Matter" devices:

https://www.home-assistant.io/blog/2022/05/29/matter-in-home-assistant-workshop-announcement/

https://www.youtube.com/watch?v=9fOHBl5w0_k

https://community.home-assistant.io/t/matter-in-home-assistant-workshop-announcement/426129/

Hedda, 2022-06-22:
@mercenaruss If have time please also see this and maybe contribute to discussion -> https://github.com/home-assistant/addons-development/issues/38

Hedda, 2022-09-27:
FYI, missed that tube0013 posted on Twitter that he uploaded a couple of OpenThread RCP firmware images for the CC2652P (TubesZB devices) CC2652R (zzh!) that could be used for initial development and testing as he confirmed those working with agners OTBR addon from addons-development so that could be of interest for those early adopters interested in Thread/Matter support inside Home Assistant:

https://twitter.com/TubesZb/status/1552823766136373251

https://github.com/tube0013/tube_gateways/tree/main/openthread_boarder_router_fw

Again more discussion about CC2652 RPC firmware support for OpenThread here:

https://github.com/home-assistant/addons-development/issues/38

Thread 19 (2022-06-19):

Wrong pin naming on the silk screen

rea-ducks, 2022-06-19:
On the silk screen of the GW-TTGO-POE v1.2 pin 6 of the 16 pin connector to the TTGO is declared as "NC". But in fact it's connected to IO16 of the ESP and RES of the RF-Star. That's also how it's identified on the schematic.

mercenaruss, 2022-06-21:
I will check and update silkscreen.

mercenaruss, 2022-09-12:
@rea-ducks Gerbers updated. Thanks

Closed 2022-09-12.

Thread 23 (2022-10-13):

Broken links in repository

letovlive, 2022-10-13:
There are broken links on the website and its crosslinks after the last files rearrange.

letovlive, 2022-10-13:
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

letovlive, 2022-10-13:
the same
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

I believe it is better to use some automated crawler to analyze broken links.

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

I've used integrity
https://apps.apple.com/us/app/integrity/id513610341?mt=12

mercenaruss, 2022-10-13:
Issues fixed,thank you for pointing out.
Now checking all broken links for all locations.

Closed 2022-10-13.

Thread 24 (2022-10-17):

Broken links in repository - letyshops

xDaemonSx, 2022-10-17:
hi

all letyshop links are not working
an example: on a page https://zig-star.com/projects/zigstar-lilyzig/#bill-of-materials
https://letyshops.com/r/aliexpress-69affae66921 - not working

same for all letyshops links

mercenaruss, 2022-10-24:
Will fix this.
Till then use device description to search on Aliexpress

Closed 2023-02-10.

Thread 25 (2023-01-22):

Use the SMA antenna with Ebyte E72-2G4M20S1E issue

phoenixxie0, 2023-01-22:
If we want to Use the SMA connector with Ebyte E72-2G4M20S1E to make the module.  To work with an external antenna, it must to cut the traces of the built-in antenna and solder the SMA connector directly to them. The built-in antenna is not intended to be used.
Like this pic
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

mercenaruss, 2023-02-10:
Correct,this is a default requirement.

Closed 2023-02-10.

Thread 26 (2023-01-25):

Password reset on ZigStar LAN Gateway

msrv, 2023-01-25:
Hi,
asking for a friend...

Is there a way to reset the http auth password for the webinterface of a LAN Gateway or to manually edit the password via terminal etc?

Thank you! :)

Edit: Nevermind, found the solution (Quote from https://github.com/xyzroe/ZigStarGW-FW/commit/7798ec383302ccfa7d23e9bdd0191deb37643cce: Power Cycle the device 5 times less than 2 secons apart

Please close this :)

Closed 2023-02-10.

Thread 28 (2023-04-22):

The latest STL files can't be opened in prusaslicer

rrozema, 2023-04-22:
An error code occurs when importing into latest PrusaSlicer (v2.5.2 on win64) the latest revisions of each of the zigstar stl files from the WT32-ETH01_LAN_Gateway folder. Previous revisions can successfully be opened and printed though.

mercenaruss, 2023-04-24:
Will check and revert here.

mercenaruss, 2024-05-07:
@rrozema unfortunately i dont have source files anymore.

Closed 2024-05-07.

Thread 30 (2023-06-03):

error handling request

nebbiadigiorno, 2023-06-03:
hi, i am tring to install a zigstar lan gateway in zha but without success.
the error in the log:

```
Logger: aiohttp.server
Source: components/zha/radio_manager.py:224
First occurred: 13:48:10 (1 occurrences)
Last logged: 13:48:10

Error handling request
Traceback (most recent call last):
  File "/usr/local/lib/python3.10/site-packages/zigpy_znp/api.py", line 1058, in request_callback_rsp
    return await callback_rsp
asyncio.exceptions.CancelledError

During handling of the above exception, another exception occurred:

Traceback (most recent call last):
  File "/usr/local/lib/python3.10/site-packages/zigpy_znp/api.py", line 253, in start_network
    commissioning_rsp = await self.request_callback_rsp(
  File "/usr/local/lib/python3.10/site-packages/zigpy_znp/api.py", line 1055, in request_callback_rsp
    async with async_timeout.timeout(timeout):
  File "/usr/local/lib/python3.10/site-packages/async_timeout/__init__.py", line 129, in __aexit__
    self._do_exit(exc_type)
  File "/usr/local/lib/python3.10/site-packages/async_timeout/__init__.py", line 212, in _do_exit
    raise asyncio.TimeoutError
asyncio.exceptions.TimeoutError

The above exception was the direct cause of the following exception:

Traceback (most recent call last):
  File "/usr/local/lib/python3.10/site-packages/aiohttp/web_protocol.py", line 433, in _handle_request
    resp = await request_handler(request)
  File "/usr/local/lib/python3.10/site-packages/aiohttp/web_app.py", line 504, in _handle
    resp = await handler(request)
  File "/usr/local/lib/python3.10/site-packages/aiohttp/web_middlewares.py", line 117, in impl
    return await handler(request)
  File "/usr/src/homeassistant/homeassistant/components/http/security_filter.py", line 85, in security_filter_middleware
    return await handler(request)
  File "/usr/src/homeassistant/homeassistant/components/http/forwarded.py", line 100, in forwarded_middleware
    return await handler(request)
  File "/usr/src/homeassistant/homeassistant/components/http/request_context.py", line 28, in request_context_middleware
    return await handler(request)
  File "/usr/src/homeassistant/homeassistant/components/http/ban.py", line 80, in ban_middleware
    return await handler(request)
  File "/usr/src/homeassistant/homeassistant/components/http/auth.py", line 235, in auth_middleware
    return await handler(request)
  File "/usr/src/homeassistant/homeassistant/components/http/view.py", line 146, in handle
    result = await result
  File "/usr/src/homeassistant/homeassistant/components/config/config_entries.py", line 180, in post
    return await super().post(request, flow_id)
  File "/usr/src/homeassistant/homeassistant/components/http/data_validator.py", line 72, in wrapper
    result = await method(view, request, data, *args, **kwargs)
  File "/usr/src/homeassistant/homeassistant/helpers/data_entry_flow.py", line 110, in post
    result = await self._flow_mgr.async_configure(flow_id, data)
  File "/usr/src/homeassistant/homeassistant/data_entry_flow.py", line 267, in async_configure
    result = await self._async_handle_step(
  File "/usr/src/homeassistant/homeassistant/data_entry_flow.py", line 367, in _async_handle_step
    result: FlowResult = await getattr(flow, method)(user_input)
  File "/usr/src/homeassistant/homeassistant/components/zha/config_flow.py", line 370, in async_step_form_initial_network
    return await self.async_step_form_new_network(user_input)
  File "/usr/src/homeassistant/homeassistant/components/zha/config_flow.py", line 376, in async_step_form_new_network
    await self._radio_mgr.async_form_network()
  File "/usr/src/homeassistant/homeassistant/components/zha/radio_manager.py", line 224, in async_form_network
    await app.form_network()
  File "/usr/local/lib/python3.10/site-packages/zigpy/application.py", line 333, in form_network
    await self.form_network(fast=True)
  File "/usr/local/lib/python3.10/contextlib.py", line 217, in __aexit__
    await self.gen.athrow(typ, value, traceback)
  File "/usr/local/lib/python3.10/site-packages/zigpy_znp/api.py", line 875, in capture_responses
    yield queue
  File "/usr/local/lib/python3.10/site-packages/zigpy_znp/api.py", line 291, in start_network
    raise zigpy.exceptions.FormationFailure(
zigpy.exceptions.FormationFailure: Network formation refused: there is too much RF interference. Make sure your coordinator is on a USB 2.0 extension cable and away from any sources of interference, like USB 3.0 ports, SSDs, 2.4GHz routers, motherboards, etc.

```

i tried on the latest versione of home assisstant.
any ideas?

mercenaruss, 2023-07-06:
What setings you are using?

mercenaruss, 2024-05-07:
Closed due inactivity.

Closed 2024-05-07.

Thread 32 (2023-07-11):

ZigiHat i2c VCC issue on RPI3b

Buuhuu, 2023-07-11:
Hey, I am using the ZigiHat on a Raspberry Pi 3 Model B rev 1.2 (not the b+ so without the PoE header) and I am trying to connect another extension board using the qwiic interface. For some reason the VCC on the i2c interface is only 2.3V (2.6V with the backup battery in place). I would expect it to be 3.3V as it is the case for the raspberry pi. The power supply of the raspberry pi itself seems stable and both 3.3V and 5V on the gpio header work as expected. It seems that the operation voltage of the whole board is only 2.3V which is in rage of what the RF module supports but also there 3.3V is recommended.

Am I doing something wrong? Is the ZigiHat only supported in RPI3b+/4 with the PoE header?

Is there any "fix" I could apply to make it work on the RPI3b? I assume just connecting i2c VCC to 3.3V is not such a good idea.

Would you mind to share the schematics of the board?

mercenaruss, 2023-09-06:
Replied to email about procedure.

Closed 2023-09-06.

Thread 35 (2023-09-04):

ESPHome and ethernet

ssolodennikov, 2023-09-04:
I am trying to make POE GW with EspHome, but cannot get ethernet working.

[D][esp-idf:000]: E (526) esp.emac: emac_esp32_init(349): reset timeout
[D][esp-idf:000]: E (526) esp_eth: esp_eth_driver_install(214): init mac failed
[E][ethernet:105]: ETH driver install error: (263) ESP_ERR_TIMEOUT
[E][component:113]: Component ethernet was marked as failed.

My ethernet config in yaml as follows:

ethernet:
  type: LAN8720
  mdc_pin: GPIO23
  mdio_pin: GPIO18
  clk_mode: GPIO0_IN
  phy_addr: 1
  power_pin: GPIO16

ssolodennikov, 2023-09-04:
Correct ethernet config for device HamGeek POE Zigbee 3.0 ois
ethernet:
  type: LAN8720
  mdc_pin: GPIO23
  mdio_pin: GPIO18
  clk_mode: GPIO17_OUT
  phy_addr: 0
  power_pin: GPIO12

Closed 2023-09-04.

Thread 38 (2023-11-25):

Tons of errors in Home Assistant ZHA with UZG-01 v0.3

kylepyke, 2023-11-25:
I'm getting so many errors and dropouts I don't know where to begin.

Here are some of the errors:

```
 Logger: zigpy.zcl
Source: runner.py:188
First occurred: 3:59:04 AM (4 occurrences)
Last logged: 3:59:04 AM

    [0xFF93:1:0x0019] Traceback (most recent call last): File "/usr/local/lib/python3.11/site-packages/zigpy/zcl/clusters/general.py", line 2191, in _handle_cluster_request await self._handle_image_block(*args, tsn=tsn, model=self.endpoint.model) File "/usr/local/lib/python3.11/site-packages/zigpy/zcl/clusters/general.py", line 2312, in _handle_image_block await self.image_block_response( File "/usr/local/lib/python3.11/site-packages/zigpy/zcl/__init__.py", line 411, in reply return await self._endpoint.reply( ^^^^^^^^^^^^^^^^^^^^^^^^^^^ File "/usr/local/lib/python3.11/site-packages/zigpy/endpoint.py", line 278, in reply return await self.device.reply( ^^^^^^^^^^^^^^^^^^^^^^^^ File "/usr/local/lib/python3.11/site-packages/zigpy/device.py", line 469, in reply return await self.request( ^^^^^^^^^^^^^^^^^^^ File "/usr/local/lib/python3.11/site-packages/zigpy/device.py", line 297, in request await self._application.request( File "/usr/local/lib/python3.11/site-packages/zigpy/application.py", line 768, in request await self.send_packet( File "/usr/local/lib/python3.11/site-packages/zigpy_znp/zigbee/application.py", line 1061, in send_packet await self._send_request_raw( File "/usr/local/lib/python3.11/site-packages/zigpy_znp/zigbee/application.py", line 952, in _send_request_raw response = await asyncio.shield( ^^^^^^^^^^^^^^^^^^^^^ File "/usr/local/lib/python3.11/site-packages/zigpy_znp/api.py", line 1067, in request_callback_rsp await self.request(request, timeout=timeout, **response_params) File "/usr/local/lib/python3.11/site-packages/zigpy_znp/api.py", line 1021, in request self._uart.send(frame) ^^^^^^^^^^^^^^^ AttributeError: 'NoneType' object has no attribute 'send'
    [0x21BF:1:0x0019] Traceback (most recent call last): File "/usr/local/lib/python3.11/site-packages/zigpy/zcl/clusters/general.py", line 2191, in _handle_cluster_request await self._handle_image_block(*args, tsn=tsn, model=self.endpoint.model) File "/usr/local/lib/python3.11/site-packages/zigpy/zcl/clusters/general.py", line 2312, in _handle_image_block await self.image_block_response( File "/usr/local/lib/python3.11/site-packages/zigpy/zcl/__init__.py", line 411, in reply return await self._endpoint.reply( ^^^^^^^^^^^^^^^^^^^^^^^^^^^ File "/usr/local/lib/python3.11/site-packages/zigpy/endpoint.py", line 278, in reply return await self.device.reply( ^^^^^^^^^^^^^^^^^^^^^^^^ File "/usr/local/lib/python3.11/site-packages/zigpy/device.py", line 469, in reply return await self.request( ^^^^^^^^^^^^^^^^^^^ File "/usr/local/lib/python3.11/site-packages/zigpy/device.py", line 297, in request await self._application.request( File "/usr/local/lib/python3.11/site-packages/zigpy/application.py", line 768, in request await self.send_packet( File "/usr/local/lib/python3.11/site-packages/zigpy_znp/zigbee/application.py", line 1061, in send_packet await self._send_request_raw( File "/usr/local/lib/python3.11/site-packages/zigpy_znp/zigbee/application.py", line 952, in _send_request_raw response = await asyncio.shield( ^^^^^^^^^^^^^^^^^^^^^ File "/usr/local/lib/python3.11/site-packages/zigpy_znp/api.py", line 1067, in request_callback_rsp await self.request(request, timeout=timeout, **response_params) File "/usr/local/lib/python3.11/site-packages/zigpy_znp/api.py", line 1021, in request self._uart.send(frame) ^^^^^^^^^^^^^^^ AttributeError: 'NoneType' object has no attribute 'send'
```

Another:

```

Logger: homeassistant
Source: /usr/src/homeassistant/homeassistant/runner.py:145
First occurred: 3:56:12 AM (22 occurrences)
Last logged: 3:59:03 AM
Error doing job: Task exception was never retrieved

Traceback (most recent call last):
  File "/usr/local/lib/python3.11/site-packages/zigpy_znp/api.py", line 1028, in request
    response = await response_future
               ^^^^^^^^^^^^^^^^^^^^^
asyncio.exceptions.CancelledError

During handling of the above exception, another exception occurred:

Traceback (most recent call last):
  File "/usr/local/lib/python3.11/site-packages/zigpy_znp/api.py", line 1067, in request_callback_rsp
    await self.request(request, timeout=timeout, **response_params)
  File "/usr/local/lib/python3.11/site-packages/zigpy_znp/api.py", line 1024, in request
    async with async_timeout.timeout(
  File "/usr/local/lib/python3.11/site-packages/async_timeout/__init__.py", line 141, in __aexit__
    self._do_exit(exc_type)
  File "/usr/local/lib/python3.11/site-packages/async_timeout/__init__.py", line 228, in _do_exit
    raise asyncio.TimeoutError
TimeoutError

```

Another:

```

Logger: zigpy_znp.zigbee.application
Source: /usr/local/lib/python3.11/site-packages/zigpy_znp/zigbee/application.py:691
First occurred: 3:59:04 AM (1 occurrences)
Last logged: 3:59:04 AM
Watchdog check failed

Traceback (most recent call last):
  File "/usr/local/lib/python3.11/site-packages/zigpy_znp/api.py", line 1028, in request
    response = await response_future
               ^^^^^^^^^^^^^^^^^^^^^
asyncio.exceptions.CancelledError

During handling of the above exception, another exception occurred:

Traceback (most recent call last):
  File "/usr/local/lib/python3.11/site-packages/zigpy_znp/zigbee/application.py", line 689, in _watchdog_loop
    await self._znp.request(c.SYS.Ping.Req())
  File "/usr/local/lib/python3.11/site-packages/zigpy_znp/api.py", line 1024, in request
    async with async_timeout.timeout(
  File "/usr/local/lib/python3.11/site-packages/async_timeout/__init__.py", line 141, in __aexit__
    self._do_exit(exc_type)
  File "/usr/local/lib/python3.11/site-packages/async_timeout/__init__.py", line 228, in _do_exit
    raise asyncio.TimeoutError
TimeoutError

```

Another:

```

Logger: zigpy_znp.zigbee.application
Source: /usr/local/lib/python3.11/site-packages/zigpy_znp/zigbee/application.py:778
First occurred: 3:59:19 AM (1 occurrences)
Last logged: 3:59:19 AM
Failed to reconnect

Traceback (most recent call last):
  File "/usr/local/lib/python3.11/site-packages/zigpy_znp/api.py", line 1028, in request
    response = await response_future
               ^^^^^^^^^^^^^^^^^^^^^
asyncio.exceptions.CancelledError

During handling of the above exception, another exception occurred:

Traceback (most recent call last):
  File "/usr/local/lib/python3.11/site-packages/zigpy_znp/zigbee/application.py", line 772, in _reconnect
    await self.connect()
  File "/usr/local/lib/python3.11/site-packages/zigpy_znp/zigbee/application.py", line 115, in connect
    await znp.connect()
  File "/usr/local/lib/python3.11/site-packages/zigpy_znp/api.py", line 726, in connect
    self.capabilities = (await self._skip_bootloader()).Capabilities
                         ^^^^^^^^^^^^^^^^^^^^^^^^^^^^^
  File "/usr/local/lib/python3.11/site-packages/zigpy_znp/api.py", line 706, in _skip_bootloader
    return await self.request(c.SYS.Ping.Req())
           ^^^^^^^^^^^^^^^^^^^^^^^^^^^^^^^^^^^^
  File "/usr/local/lib/python3.11/site-packages/zigpy_znp/api.py", line 1024, in request
    async with async_timeout.timeout(
  File "/usr/local/lib/python3.11/site-packages/async_timeout/__init__.py", line 141, in __aexit__
    self._do_exit(exc_type)
  File "/usr/local/lib/python3.11/site-packages/async_timeout/__init__.py", line 228, in _do_exit
    raise asyncio.TimeoutError
TimeoutError
```

Another:

```
Logger: zigpy.application
Source: runner.py:188
First occurred: 2:48:29 AM (13 occurrences)
Last logged: 2:49:04 AM

    Received relays from an unknown device: 0xFF93
    Unknown device AddrModeAddress(addr_mode=<AddrMode.NWK: 2>, address=0xFF93)
    Unknown device AddrModeAddress(addr_mode=<AddrMode.NWK: 2>, address=0x9D70)
    Received relays from an unknown device: 0xA995
    Unknown device AddrModeAddress(addr_mode=<AddrMode.NWK: 2>, address=0xA995)
```

I've been trying to work this out for days, and cannot get this coordinator to function properly. It constantly disconnects and needs to be restarted. There seems to be MAJOR issues that need to be addressed.

Some people have had similar issues– seemingly with the CC2652P/P7 chip:

https://github.com/home-assistant/core/issues/94381

https://community.home-assistant.io/t/tubeszb-cc2652p2-keeps-disconnecting-from-ha-since-zigbee2mqtt-last-update/538064/1

This link demonstrates a fix for the Sonoff-P dongle, but I'm not sure how it would be implemented with a ZigStar device:
https://community.home-assistant.io/t/zigbee2mqtt-not-starting-up-anymore/336312?u=lexcao

Please Advise.

mercenaruss, 2024-05-07:
@kylepyke follow this thread and flash last firmware from Koenkk: https://github.com/Koenkk/Z-Stack-firmware/discussions/496

Closed 2024-05-07.

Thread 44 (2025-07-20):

Tuya Water Leak Detector can't connect

sipi58, 2025-07-20:
I use a ZigStar LAN Gateway with a Tuya Water Leak sensor I bought years ago and they work great. This is another older Tuya TS0207.

I just bought e new Tuya Zigbee Smart Water Leak Detector and I tried to pairing with Z2M but it can't connect and no entry in the log. There is no identifying information on the box or device. The PCB is marked as follows:
IHSENSO wsensor-IC-V2

Pairing
In Z2M, set the option to Allow Connection (All).
On the Tuya device, press the Reset button for more than 5 seconds (the LED will flash) and check the connected devices in Z2M.
Nothing happens, the device does not appear.

What could be the cause of the problem and how can it be fixed?

Thank you for your help

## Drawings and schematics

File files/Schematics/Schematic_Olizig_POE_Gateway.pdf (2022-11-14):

## GND

## RF-BM-2652P2

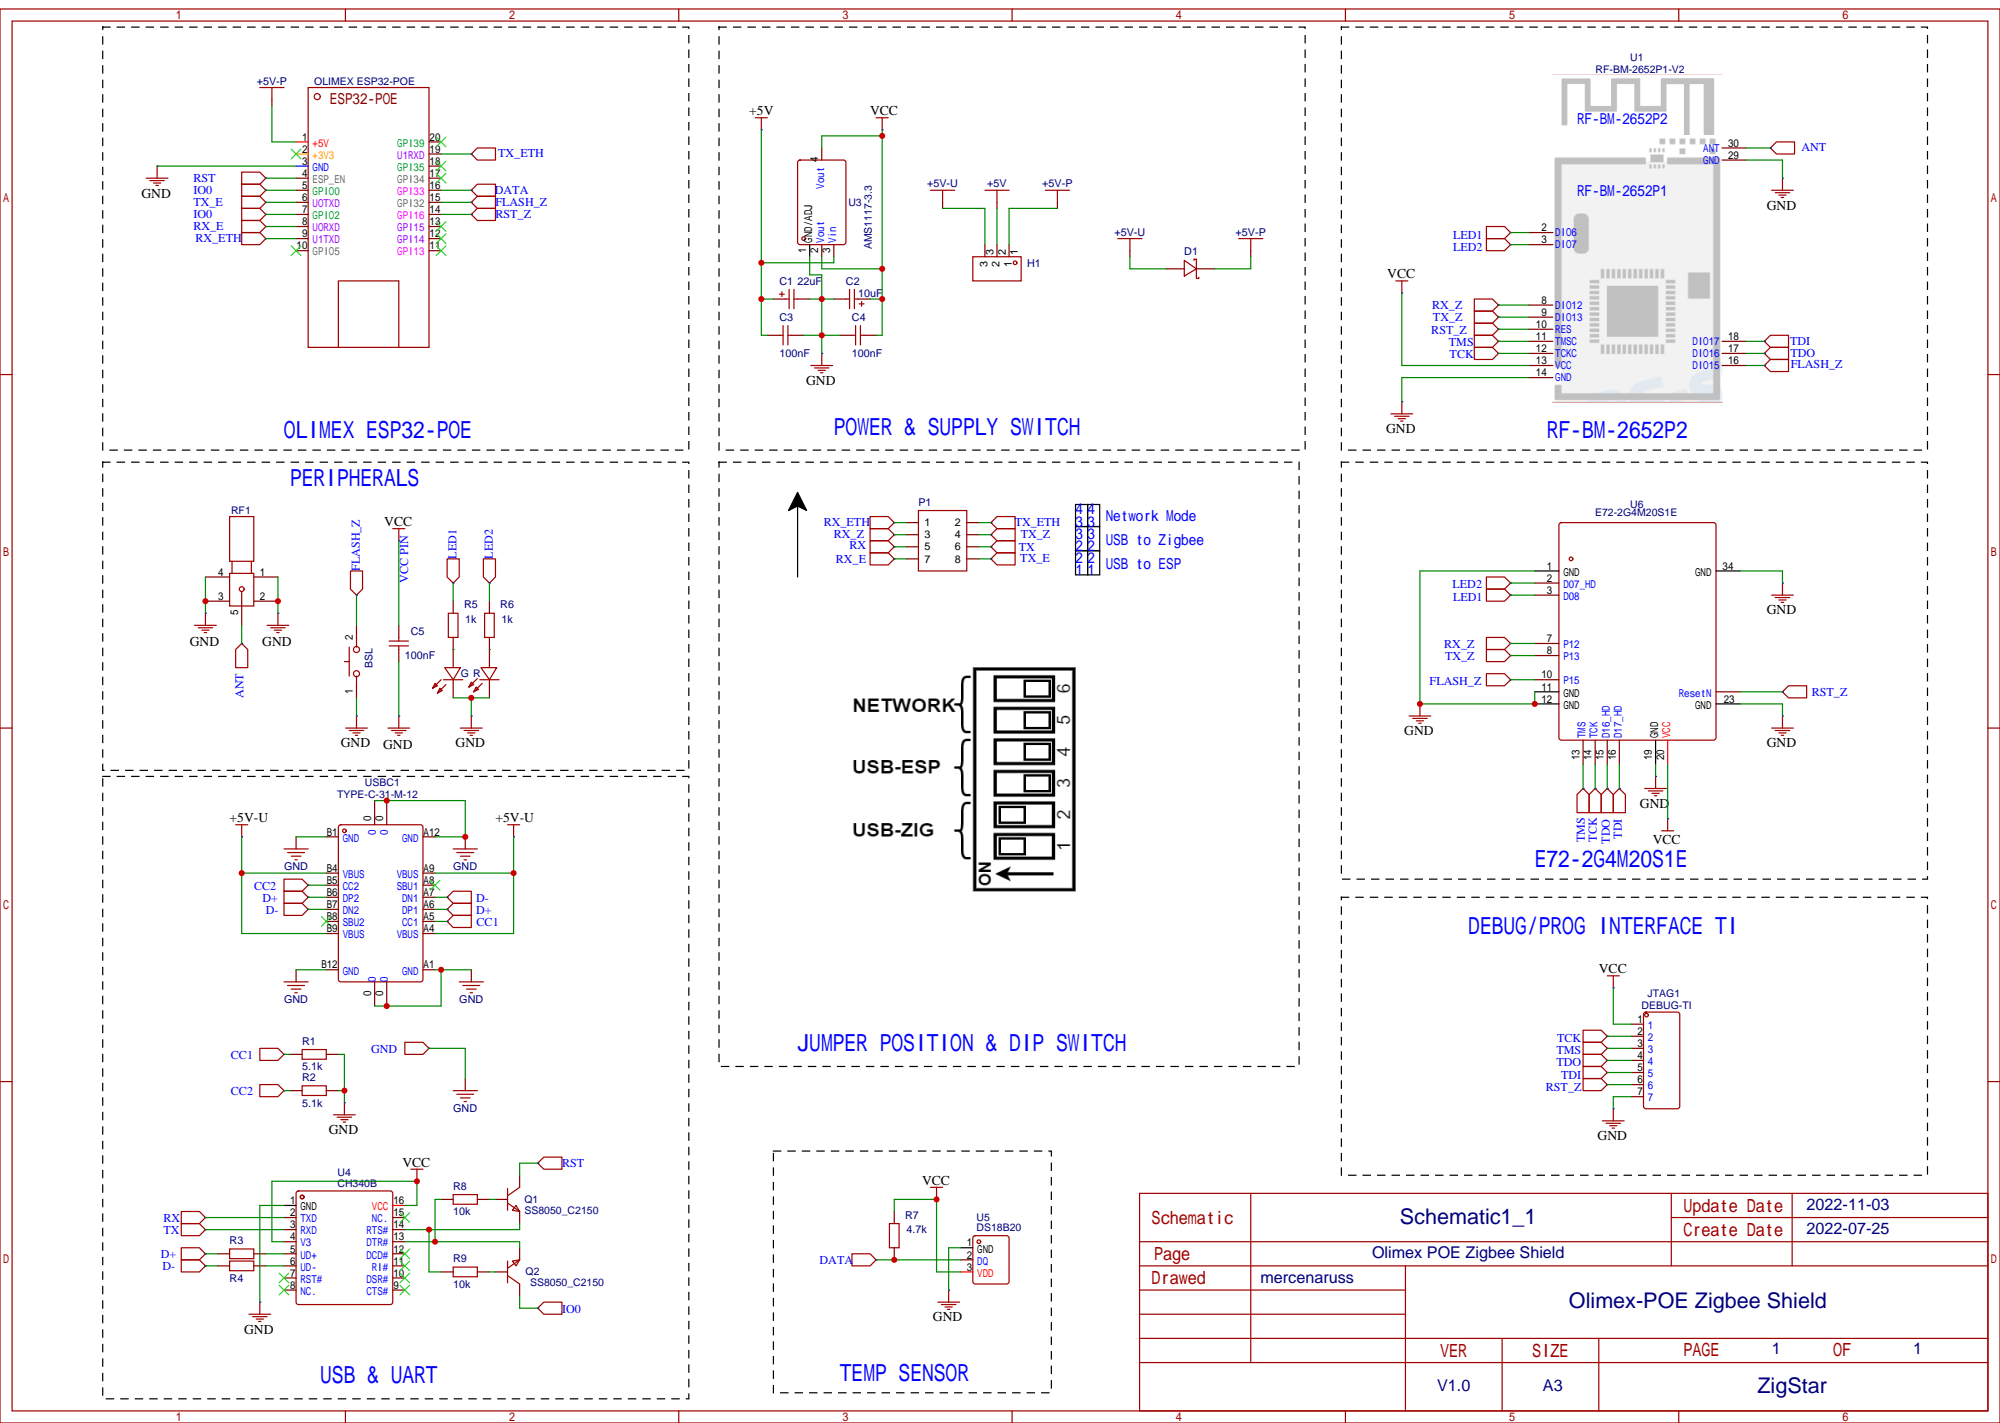
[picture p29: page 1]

DEBUG/PROG INTERFACE TI

JUMPER POSITION & DIP SWITCH

Schematic1_1
Olimex POE Zigbee Shield

Olimex-POE Zigbee Shield

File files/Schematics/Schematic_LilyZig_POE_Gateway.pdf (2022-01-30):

# TTGO POE

## GPIO39

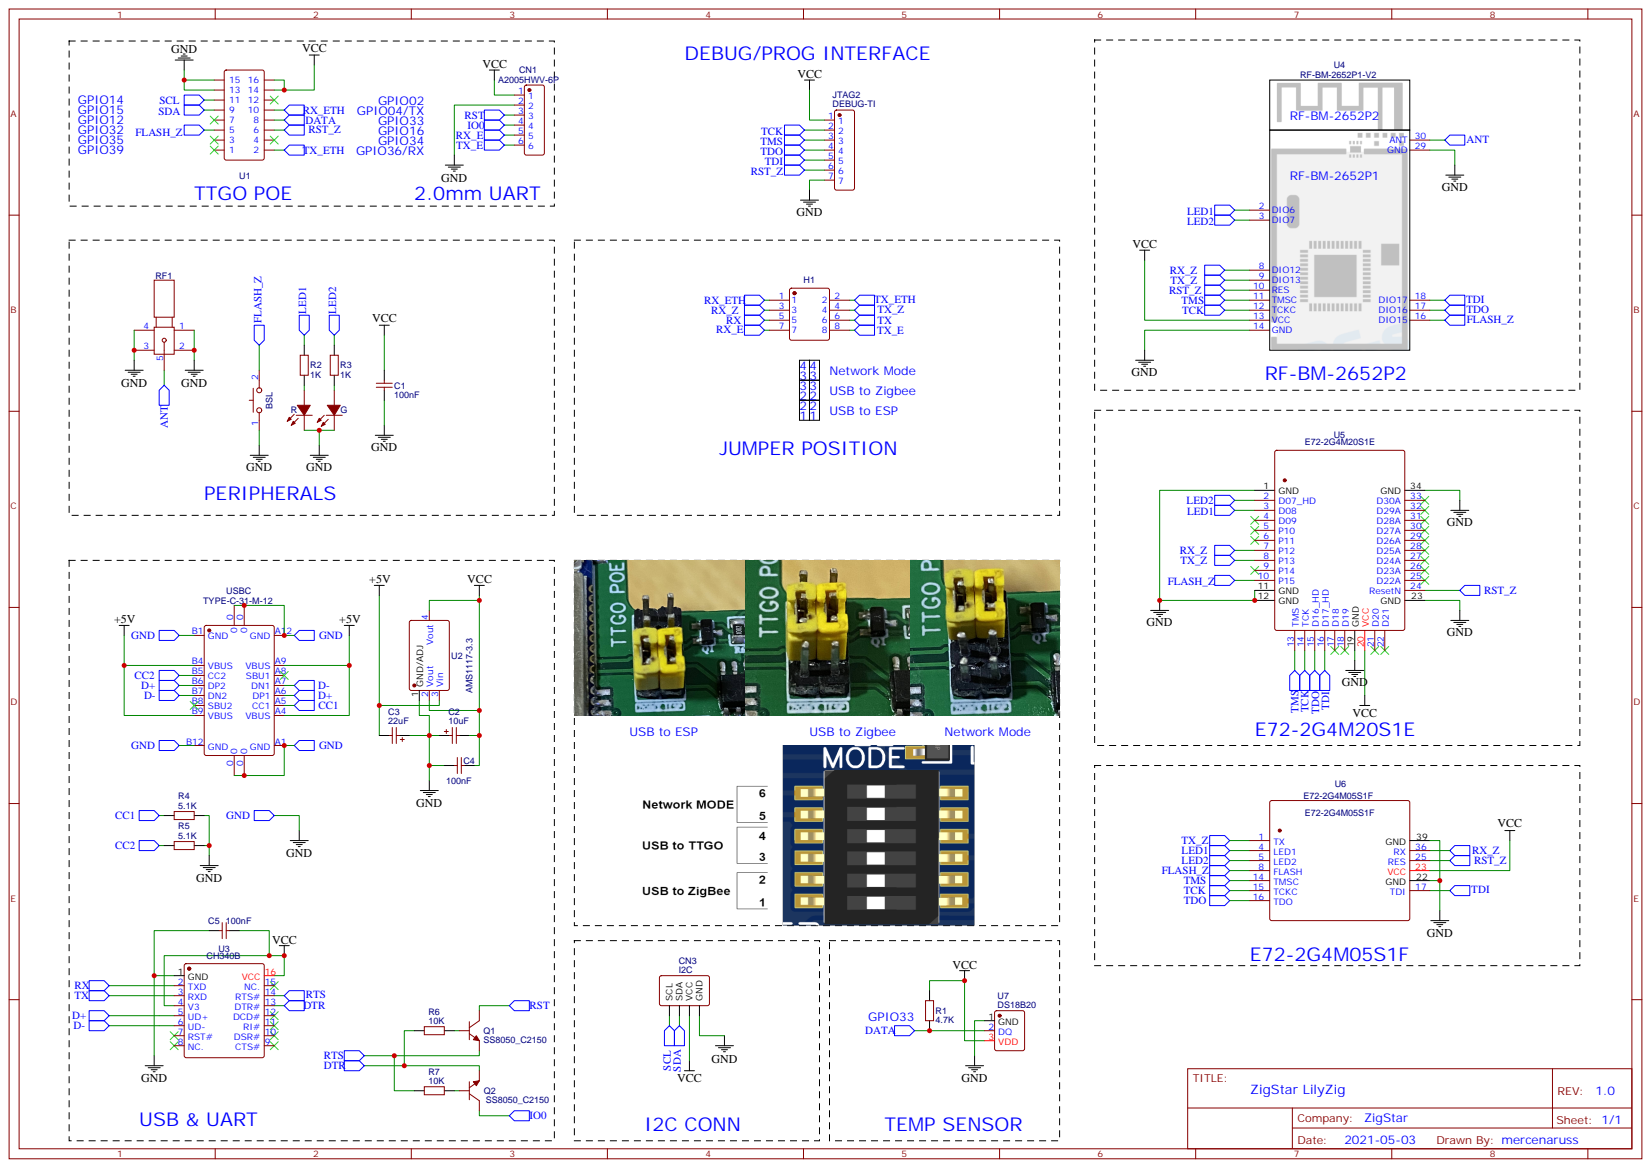
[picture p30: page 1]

DSR# 10 RI# 11 DCD# 12 DTR# 13 RTS# 14 NC. 15 VCC 16

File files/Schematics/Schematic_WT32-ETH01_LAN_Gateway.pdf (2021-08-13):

## RF-BM-2652P2

## RF-BM-2652P1

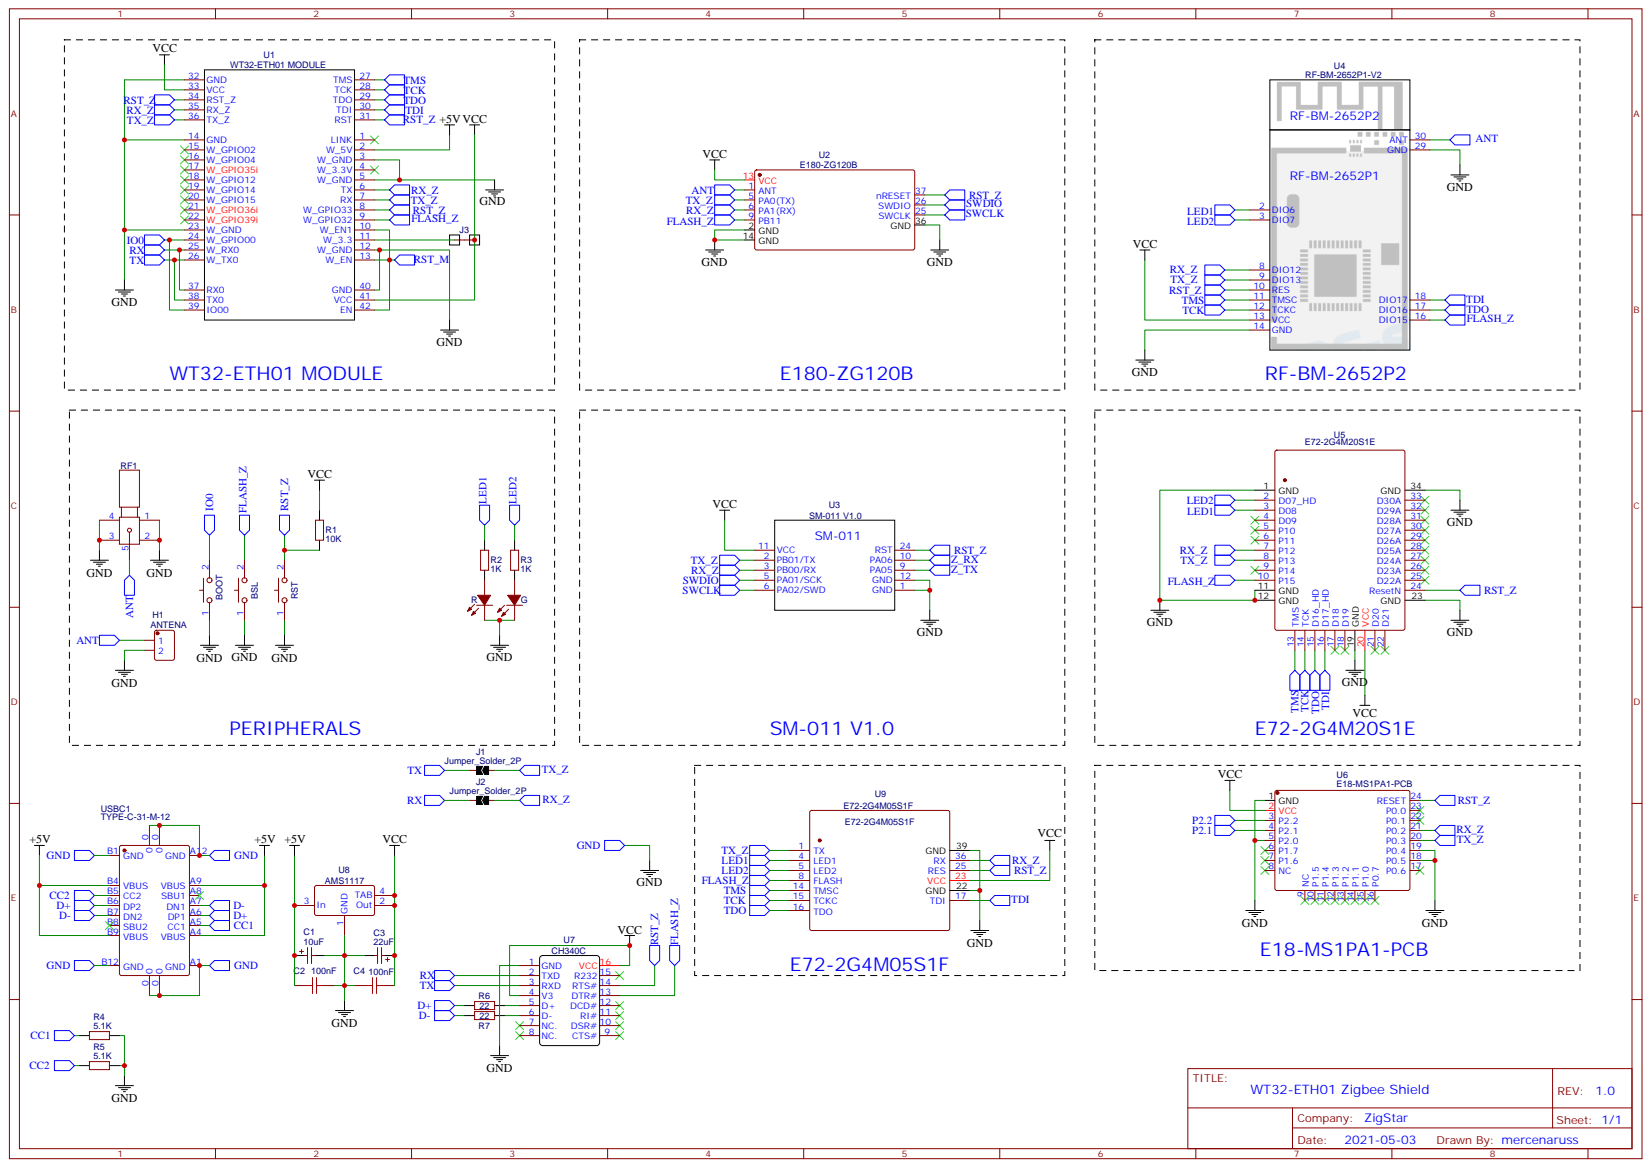
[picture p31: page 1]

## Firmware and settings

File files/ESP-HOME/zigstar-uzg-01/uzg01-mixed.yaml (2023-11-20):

substitutions:
  #Name your Gateway
  device_name: uzg01-mixed
  #Home Assistant Name
  friendly_name: UZG Gateway - Mixed
  #Secret YAML is used for next data:
  #pi_pw: !secret api_password
  #ota_pw: !secret ota_password

esphome:
  name: "${device_name}"
  name_add_mac_suffix: false
  project:
    name: ZigStar.UZG01-Mixed
    version: "1.0"
  on_boot:
    priority: 600
    then:
      - switch.turn_on: zRST_gpio
      - delay: 15ms
      - switch.turn_off: zRST_gpio

esp32:
  board: esp32dev
  framework:
    type: esp-idf
    sdkconfig_options:
      CONFIG_FREERTOS_UNICORE: y
      CONFIG_ESP_TASK_WDT_TIMEOUT_S: "10"

ethernet:
  type: LAN8720
  mdc_pin: GPIO23
  mdio_pin: GPIO18
  clk_mode: GPIO17_OUT
  phy_addr: 0
  power_pin: GPIO05

## General ESPHome settings
# Home Assistant API is enabled
api:
  #password: ${api_pw}
  reboot_timeout: 0s
# Logger is enabled
logger:
  level: DEBUG
# Enable OTA
ota:
  #password: ${ota_pw}
# Enable WEB
web_server:
  port: 80

dashboard_import:
  package_import_url: github://mercenaruss/zigstar_gateways/files/ESP-HOME/zigstar-uzg-01/uzg01-mixed.yaml@main
  import_full_config: true

# BTProxy
esp32_ble_tracker:
  scan_parameters:
    interval: 1100ms
    window: 1100ms
    active: true

bluetooth_proxy:
  active: true

##Uptime generic sensor
sensor:
  - platform: uptime
    id: uptime_s
    update_interval: 60s
# Enable HA Time
time:
  - platform: homeassistant
    id: homeassistant_time

#External component Stream Server
external_components:
  - source: github://tube0013/esphome-stream-server-v2

#CONTROL SETTINGS

## Buttons
button:
  - platform: safe_mode
    name: 3.3.Safe Mode Reboot
    entity_category: diagnostic
  ### Zigbee Restart
  - platform: template
    name: "3.2.Zigbee - Restart"
    icon: mdi:restart
    id: zRST
    on_press:
      - switch.turn_on: zRST_gpio
      - delay: 15ms
      - switch.turn_off: zRST_gpio
  ### ESP32 Restart
  - platform: restart
    name: "3.1.ESP32 - Restart"
  ### Zigbee Flash Mode
  - platform: template
    name: "2.1.Zigbee - Flash Mode"
    icon: mdi:cellphone-arrow-down
    on_press:
      - script.execute: fw_update_mode

##Status of physical button - sensor
binary_sensor:
  - platform: gpio
    name: "4.1.Physical button status"
    icon: mdi:toggle-switch
    id: gpio35btn1
    pin:
      number: GPIO35
      mode:
        input: true
      inverted: yes
    on_press:
      then:
        - switch.toggle: modeSwitchTemplate
  ## Socket connection status
  - platform: stream_server
    stream_server: s_s
    name: "4.2.Z2M/ZHA Connected"

## Switches
switch:
### CC2652P Restart
  - platform: gpio
    pin: 16
    id: zRST_gpio
    inverted: yes
    restore_mode: ALWAYS_OFF

### Zigbee CC2652P to flash mode switch      
  - platform: gpio
    pin: 32
    name: "Zigbee Flash Mode internal"
    icon: mdi:toggle-switch
    id: zBSL
    inverted: yes
    restore_mode: ALWAYS_OFF
    internal: true
    
### Mode LAN/USB switch
  - platform: template
    name: "1.0.UZG-01 MODE SWITCH (LAN|OFF| / USB|ON|)"
    id: modeSwitchTemplate
    turn_on_action:
      - switch.turn_on: gpio12LED1
      - switch.turn_on: gpio4Select
      - switch.template.publish:
          id: modeSwitchTemplate
          state: ON
    turn_off_action:
      - switch.turn_off: gpio12LED1
      - switch.turn_off: gpio4Select
      - switch.template.publish:
          id: modeSwitchTemplate
          state: OFF

  - platform: gpio
    name: "DEVICE MODE SWITCH (LAN|OFF| / USB|ON|)"
    restore_mode: ALWAYS_OFF
    icon: mdi:toggle-switch
    internal: true
    id: gpio4Select
    pin:
      number: GPIO33

### LEDs swithces
  - platform: gpio
    name: "2.3.Mode LED (RED)"
    restore_mode: ALWAYS_OFF
    icon: mdi:toggle-switch
    id: gpio12LED1
    pin:
      number: GPIO12

  - platform: gpio
    name: "2.2.Power LED (BLUE)"
    restore_mode: ALWAYS_ON
    icon: mdi:toggle-switch
    id: gpio14LED2
    pin:
      number: GPIO14

#Update CC2652 Firmware
script:
  - id: fw_update_mode
    then:
      - switch.turn_on: zBSL
      - delay: 1s
      - switch.turn_on: zRST_gpio
      - delay: 1s
      - switch.turn_off: zRST_gpio
      - logger.log: "Delaying 4 seconds for TI chip to be ready"
      - delay: 4s
      - switch.turn_off: zBSL
      - logger.log: "Update with cc2538-bsl tool now!"
      - logger.log: "Usage: cc2538-bsl.py -p socket://ip_or_hostname:6638 -evw firmware.hex"

#UART Settings
uart:
  id: uart_bus
  rx_pin: GPIO36
  tx_pin: GPIO04
  baud_rate: 115200

#Serial Bridge Settings,uncomment #port to change default 6638 TCP port
stream_server:
  uart_id: uart_bus
  id: s_s
#  port: 1234

mdns:
  services:
    - service: "_uzg-01"
      protocol: "_tcp"
      port: 6638
      txt:
        version: 1.0
        name: UZG-01
        radio_type: znp
        baud_rate: 115200
        data_flow_control: software

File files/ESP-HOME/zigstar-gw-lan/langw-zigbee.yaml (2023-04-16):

substitutions:
  #Name your Gateway
  device_name: langw-zigbee
  #Home Assistant Name
  friendly_name: ZS Gateway - Zigbee
  #Secret YAML is used for next data:
  #pi_pw: !secret api_password
  #ota_pw: !secret ota_password

esphome:
  name: "${device_name}"
  name_add_mac_suffix: true
  project:
    name: langw.zigbee
    version: "1.0"

esp32:
  board: esp32dev
  framework:
    type: arduino

#Ethernet connection information
ethernet:
  type: LAN8720
  mdc_pin: GPIO23
  mdio_pin: GPIO18
  clk_mode: GPIO0_IN
  phy_addr: 1
  power_pin: GPIO16

## General ESPHome settings
# Home Assistant API is enabled
api:
  #password: ${api_pw}
  reboot_timeout: 0s
# Logger is enabled
logger:
  level: DEBUG
# Enable OTA
ota:
  #password: ${ota_pw}
# Enable WEB
web_server:
  port: 80
# Enable HA Time
time:
  - platform: homeassistant
    id: homeassistant_time

#External component Stream Server
external_components:
  - source: github://mercenaruss/esphome-stream-server

# Extra sensor to keep track of gateway uptime
text_sensor:
  - platform: template
    name: "${friendly_name} Uptime"
    lambda: |-
      uint32_t dur = id(uptime_s).state;
      int dys = 0;
      int hrs = 0;
      int mnts = 0;
      if (dur > 86399) {
        dys = trunc(dur / 86400);
        dur = dur - (dys * 86400);
      }
      if (dur > 3599) {
        hrs = trunc(dur / 3600);
        dur = dur - (hrs * 3600);
      }
      if (dur > 59) {
        mnts = trunc(dur / 60);
        dur = dur - (mnts * 60);
      }
      char buffer[17];
      sprintf(buffer, "%ud %02uh %02um %02us", dys, hrs, mnts, dur);
      return {buffer};
    icon: mdi:clock-start
    update_interval: 60s

#Uptime
sensor:
  - platform: uptime
    id: uptime_s
    update_interval: 60s

# Device functions:
switch:
  - platform: restart
    name: "Gateway Restart"

  - platform: gpio
    pin: 33
    id: zRST_gpio
    inverted: yes
    restore_mode: ALWAYS_OFF
  - platform: template
    name: "Zigbee RST"
    icon: mdi:toggle-switch
    id: zRST
    turn_on_action:
      - switch.turn_on: zRST_gpio
      - delay: 15ms
      - switch.turn_off: zRST_gpio
      
  - platform: gpio
    pin: 32
    name: "Zigbee BSL"
    icon: mdi:toggle-switch
    id: zBSL
    inverted: yes
    restore_mode: ALWAYS_OFF
    internal: true
    
  - platform: template
    name: "Firmware Update"
    icon: mdi:cellphone-arrow-down
    turn_on_action:
      - script.execute: fw_update_mode
    turn_off_action:
      - switch.toggle: zRST

#Update CC2652 Firmware
script:
  - id: fw_update_mode
    then:
      - switch.turn_on: zBSL
      - delay: 1s
      - switch.turn_on: zRST_gpio
      - delay: 1s
      - switch.turn_off: zRST_gpio
      - logger.log: "Delaying ~5 seconds for TI chip to be ready"
      - delay: 5s
      - switch.turn_off: zBSL
      - logger.log: "Update with cc2538-bsl tool now!"
      - logger.log: "Usage: cc2538-bsl.py -p socket://ip_or_hostname:6638 -evw firmware.hex"

#UART Settings
uart:
  id: uart_bus
  rx_pin: GPIO5
  tx_pin: GPIO17
  baud_rate: 115200

#Serial Bridge Settings,uncomment #port to change default 6638 TCP port
stream_server:
  uart_id: uart_bus
#  port: 1234

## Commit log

2021-08-13 Not significative changes
    Some changes of copper ground
2021-08-30 Add STL for WT32-LAN Gateway
    Design by Alex.F
    [Body by Alex.F.stl, Cover by Alex.F.stl]
2021-09-01 Update Cover by Alex.F.stl
    [Cover by Alex.F.stl]
2021-09-04 Update 3D Printed Case
    [Body by Alex.F.stl, Cover by Alex.F with ventilation.stl, Cover by Alex.F.stl]
2021-10-13 Update STL's
    Add Cover for both 1.2mm PCB and 1.6mm PCB
    [Cover 1.2mm PCB by Alex.F.stl, Cover 1.6mm PCB by Alex.F.stl, Cover by Alex.F with ventilation.stl]
2021-10-17 Added Gerber for E72-2G4M20S1E
    Added Gerber for E72-2G4M20S1E (+20dbm)
2021-11-04 Update Scripts(test mode)
    [zigihat.cfg]
2021-11-04 Script update
    [zigihat.cfg]
2022-01-30 Add LilyZig v1.0
    [BOM_TTGO_RF-BM-2652P2.csv]
2022-02-23 Add LilyZig Enclosure
    [TTGO_case_v2.stl, TTGO_cover_v2.stl]
2022-03-10 Update TTGO Gerbers
    - Fixed DS18B20,Resistor Connection to strapping pin of TTGO
    - Fixed incorrect mask for C2,C3
2022-09-10 Rearrange files in folder
    [Cover 1.2mm PCB by Alex.F_sales.stl, Cover 1.6mm PCB by Alex.F_self_assembly.stl]
2022-09-12 Update Gerbers
    Update silkscreen
2022-11-14 Olimex PoE Gateway
    [BOM_Olimex_RF-BM-2652P2.xlsx]
2023-04-12 Update retired devices
